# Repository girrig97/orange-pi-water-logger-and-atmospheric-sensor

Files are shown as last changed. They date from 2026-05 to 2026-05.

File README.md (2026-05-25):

# Orange Pi Water Logger

This starter project logs water-condition readings to a CSV file on the Orange Pi microSD card every 6 hours.

Variant branch: this branch includes shared logger code for Orange Pi Zero 3 and Orange Pi 5 Max. The EC25-AU cellular modem, SMS alerts, server status updates, and daily status reporting are optional and are skipped automatically when no modem/SIM is detected. See [docs/orange-pi-5-max-ec25-au.md](docs/orange-pi-5-max-ec25-au.md).

On the cellular branch, SMS alert recipients can be changed from the Android app using `Get SMS Numbers` and `Save SMS Numbers`.

## Design brief

Build a field-ready freshwater monitoring recorder that can run unattended from a USB power bank, store week-by-week CSV logs on microSD, and remain usable even when individual probes or optional hardware are disconnected.

Core requirements:

- Support both Orange Pi Zero 3 and Orange Pi 5 Max as the main logger.
- Use a Raspberry Pi Pico or Pico W as the always-on low-power time and power controller.
- Power the Orange Pi only when needed for scheduled logging, download mode, pairing mode, or manual checks.
- Record freshwater sensor data every 6 hours by default.
- Switch to hourly recording when barometric pressure is low or dropping quickly.
- Store records on the Orange Pi microSD card as weekly CSV files.
- Keep logging partial records if a sensor is damaged, disconnected, or not installed.
- Tag failed sensor reads with clear status values instead of stopping the logger.
- Build a sensor baseline from early successful readings so missing optional sensors do not create repeated fault alerts.
- Allow field access from an Android phone over Bluetooth for status, time sync, live readings, CSV downloads, SMS number settings, signal checks, and test SMS.
- Make cellular reporting optional. If no EC25-AU modem or usable SIM is detected, skip SMS work and continue normal logging.
- Send optional daily SMS status, server updates, and unsafe-water alerts when the EC25-AU modem is installed and ready.

Field-use behavior:

- Power-on should automatically start the correct mode without terminal access.
- Normal wake: Pico powers the Orange Pi, the logger writes one row, sends the next interval to the Pico, syncs data, and shuts down.
- Short button press: Pico starts download mode and keeps the Orange Pi awake for Bluetooth access.
- Long button hold: Pico starts pairing mode.
- 10-second hold while awake: manual power-off fallback.
- After Bluetooth download or resume, mode markers are cleared so the next wake returns to unattended logging.

Reliability considerations:

- CSV writes are flushed and fsynced.
- Weekly CSV files reduce the impact of single-file corruption.
- The UART link between Orange Pi and Pico is required for adaptive wake timing, but logger shutdown still continues if the UART notification fails.
- All grounds must be common.
- Orange Pi GPIO and ADS1115 inputs must stay within 3.3V logic/input limits.
- Probe modules need calibration before readings should be treated as meaningful.
- The enclosure, cable glands, connectors, and sensor electronics must be protected against water ingress and condensation.

## Sensors included

- pH
- TDS
- Turbidity
- DS18B20 temperature
- ORP
- Dissolved oxygen
- Ammonium ISE
- BME280 ambient temperature, humidity, and pressure

## Calculated values

- EC from TDS
- Estimated salinity
- Water clarity percent
- Dissolved oxygen saturation percent
- Toxic ammonia NH3 estimate from ammonium, pH, and temperature
- Ammonia risk label
- Overall water score and condition label
- Ambient dew point
- Air/water temperature difference
- Adaptive next logging interval from barometric pressure

## Materials

Core computer and power:

| Qty | Item | Notes |
| ---: | --- | --- |
| 1 | Orange Pi Zero 3 or Orange Pi 5 Max | Main logger, stores CSV on microSD |
| 1 | microSD card | 16GB or larger recommended |
| 1 | Raspberry Pi Pico or Pico W | Low-power timer and download-mode button controller |
| 1 | USB power bank | 10,000mAh minimum; larger is better |
| 1 | 5V relay or MOS power-switch module | Pico-controlled switch for Orange Pi 5V; rated at least 3A, preferably 5A |
| 1 | DS3231 RTC module | Keeps accurate time for the Pico controller |
| 1 | Momentary self-reset illuminated button | Use `NO` and `C` for the button signal; LED terminals are separate |
| 1 | Weatherproof enclosure | Large enough for Orange Pi, Pico, ADCs, and wiring |

Sensor and interface modules:

| Qty | Item | Notes |
| ---: | --- | --- |
| 2 | ADS1115 ADC modules | I2C analog inputs for Orange Pi |
| 1 | pH sensor board and BNC pH probe | Analog output to ADS1115 |
| 1 | TDS sensor meter V1.0 board and probe | Analog output to ADS1115 |
| 1 | Turbidity sensor module and probe | Analog output to ADS1115 |
| 1 | Waterproof DS18B20 temperature probe | Digital 1-Wire temperature |
| 1 | ORP sensor module and BNC ORP probe | Analog output to ADS1115 |
| 1 | Gravity analog dissolved oxygen sensor kit | Analog output to ADS1115 |
| 1 | NH4+ ammonium ISE probe | BNC probe |
| 1 | High-impedance ISE interface amplifier | Required between NH4+ probe and ADS1115 |
| 1 | BME280 I2C sensor module | Ambient air temperature, humidity, and barometric pressure |

Wiring and protection:

| Qty | Item | Notes |
| ---: | --- | --- |
| 1 | 4.7k resistor | DS18B20 data pull-up to 3.3V |
| Assorted | Jumper wires or hookup wire | Use reliable connectors for field use |
| Assorted | Screw terminals or waterproof connectors | Makes sensor replacement easier |
| Assorted | Heat shrink tubing | Strain relief and insulation |
| Assorted | Cable glands | For waterproof enclosure cable exits |
| As needed | Voltage divider resistors or level shifters | Required if sensor analog output can exceed 3.3V |
| 2 | UART link wires between Orange Pi and Pico | Required for download button requests and adaptive wake timing |
| Optional | Small fuse or resettable polyfuse | Protection on 5V power line |
| Optional | Desiccant pack | Helps reduce moisture in enclosure |

Calibration and maintenance:

| Qty | Item | Notes |
| ---: | --- | --- |
| 1 set | pH buffer solutions | pH 4.00, 7.00, and 10.00 |
| 1 | TDS calibration solution | Common examples: 342ppm or 1000ppm |
| 1 | ORP calibration solution | Match your ORP probe/module instructions |
| 1 | Dissolved oxygen calibration supplies | Follow Gravity DO kit instructions |
| 1 set | NH4+ ISE calibration standards | At least two known concentrations |
| 1 | Distilled or deionized water | Rinsing probes between calibration steps |
| Optional | Cleaning/storage solutions | Especially for pH, ORP, DO, and ISE probes |

## Hardware shape

Use two ADS1115 ADC boards on the Orange Pi I2C header. The code auto-detects likely I2C buses for Orange Pi Zero 3 and Orange Pi 5 Max. Set `I2C_BUS_NUMBER` only if you want to force a specific bus.

## Wiring diagram

Wiring diagram

PCB carrier design notes are in [docs/pcb-carrier-design-brief.md](docs/pcb-carrier-design-brief.md).
The first Zero 3 KiCad carrier scaffold is in [hardware/zero3-carrier](hardware/zero3-carrier).

Key things to double-check before powering on:

- The 5V power-switch module input connects to the USB power bank 5V, not to a Pico GPIO pin.
- The 5V power-switch module GND is on the common ground bus.
- Pico `GP15` drives only the power-switch trigger / enable / signal / `IN` pin.
- Pico `GP14` connects only to the download button, not to the power switch.
- ADS1115 #1 has `ADDR -> GND` for address `0x48`.
- ADS1115 #2 has `ADDR -> 3.3V` for address `0x49`.
- Any sensor analog output above 3.3V needs level scaling before the ADS1115 input.

The numbered badges in the image match the legend table below. Recheck the power-switch section carefully before building, because relay and MOS boards use different terminal names.

Corrected numbered wiring:

| Number | Correct connection |
| --- | --- |
| 1 | USB-C/power-bank 5V to the PCB input; protected 5V feeds Pico VSYS and the MOSFET switch input |
| 2 | Common GND bus to Pico GND, power-switch GND, Orange Pi GND, ADC GND, sensor GND |
| 3 | Pico `GP15` to power-switch trigger/enable input |
| 4 | Pico `GP14` to button `NO`; button `C` to common GND |
| 5 | Pico `GP4` to DS3231 SDA |
| 6 | Pico `GP5` to DS3231 SCL |
| 7 | Pico `3V3` to DS3231 VCC |
| 8 | MOSFET switched 5V output to Orange Pi 5V input, pin 2 or 4 |
| 9 | Power-switch output/common GND to Orange Pi GND, pin 6 |
| 10 | Orange Pi pin 1 `3.3V` to ADS1115 VDD and DS18B20 VCC |
| 11 | Orange Pi pin 3 SDA to both ADS1115 SDA pins |
| 12 | Orange Pi pin 5 SCL to both ADS1115 SCL pins |
| 13 | Orange Pi pin 7 PC9/GPIO7 to DS18B20 data, with 4.7k pull-up to 3.3V |
| 14 | ADS1115 #1 A0 to pH analog output |
| 15 | ADS1115 #1 A1 to TDS analog output |
| 16 | ADS1115 #1 A2 to turbidity analog output |
| 17 | ADS1115 #1 A3 to ORP analog output |
| 18 | ADS1115 #2 A0 to dissolved oxygen analog output |
| 19 | ADS1115 #2 A1 to ammonium ISE amplifier analog output |
| 20 | ADS1115 #2 A2 spare |
| 21 | ADS1115 #2 A3 spare |

Corrected wiring view:

```text
                                  USB POWER BANK
                                5V OUT      GND
                                  |          |
                                  |          +-------------------- COMMON GND BUS
                                  |                               |
                                  v                               |
                    +-----------------------------+               |
                    | Raspberry Pi Pico / Pico W  |               |
                    |                             |               |
                    | VSYS/USB <- 5V power bank   |               |
                    | GND ------ COMMON GND BUS --+               |
                    | GP15 ---- power enable ----------------+    |
                    | GP14 ---- button NO/C ---- GND          |    |
                    | GP4  ---- DS3231 SDA                   |    |
                    | GP5  ---- DS3231 SCL                   |    |
                    | 3V3  ---- DS3231 VCC                   |    |
                    +-----------------------------+           |    |
                                                              |    |
                                  +---------------------------+    |
                                  v                                |
                         +------------------+                      |
                         | 5V POWER SWITCH   |                      |
                         | TRIG/EN <- GP15  |                      |
                         | IN+ <- bank 5V   |                      |
                         | IN- <- GND bus --+----------------------+
                         | OUT+ -> OPi 5V   |
                         | OUT- -> OPi GND  |
                         +------------------+
                                  |
                                  v
                    +-----------------------------+
                    | Orange Pi Zero 3            |
                    | Pin 2/4 5V <- switched 5V   |
                    | Pin 6 GND  -> common GND    |
                    | Pin 1 3.3V -> 3.3V rail     |
                    | Pin 3 SDA  -> I2C SDA rail  |
                    | Pin 5 SCL  -> I2C SCL rail  |
                    | Pin 7 PC9  -> DS18B20 DATA  |
                    +-----------------------------+
                         |        |        |
                         |        |        +---------------- I2C SCL rail
                         |        +------------------------- I2C SDA rail
                         +---------------------------------- 3.3V rail

      3.3V rail ----------------+----------------------+----------------------+
                                |                      |                      |
                                v                      v                      v
                    +-------------------+  +----------------------+  +----------------------+
                    | ADS1115 #1        |  | ADS1115 #2           |  | DS18B20 temp probe   |
                    | ADDR -> GND       |  | ADDR -> 3.3V/VDD     |  | Red/VCC -> 3.3V      |
                    | address 0x48      |  | address 0x49         |  | Black/GND -> GND     |
                    | VDD -> 3.3V       |  | VDD -> 3.3V          |  | Yellow/DATA -> OPi 7 |
      GND bus ---->| GND -> GND        |  | GND -> GND           |  | 4.7k DATA -> 3.3V    |
      SDA rail --->| SDA -> OPi pin 3   |  | SDA -> OPi pin 3     |  +----------------------+
      SCL rail --->| SCL -> OPi pin 5   |  | SCL -> OPi pin 5     |
                    | A0 <- pH AO        |  | A0 <- DO AO          |
                    | A1 <- TDS AO       |  | A1 <- NH4 ISE AO     |
                    | A2 <- turbidity AO |  | A2 spare             |
                    | A3 <- ORP AO       |  | A3 spare             |
                    +-------------------+  +----------------------+
                              ^     ^     ^     ^            ^          ^
                              |     |     |     |            |          |
                              |     |     |     |            |          |
       +----------------------+     |     |     |            |          |
       |                            |     |     |            |          |
+-------------+              +-------------+ +-------------+ +-------------+ +------------------+
| pH module   |              | TDS module  | | Turbidity   | | ORP module  | | Gravity DO       |
| VCC -> 5V*  |              | VCC -> 5V*  | | VCC -> 5V*  | | VCC -> 5V*  | | VCC -> 3.3-5V*   |
| GND -> GND  |              | GND -> GND  | | GND -> GND  | | GND -> GND  | | GND -> GND       |
| AO -> A0    |              | AO -> A1    | | AO -> A2    | | AO -> A3    | | AO -> ADS #2 A0  |
| BNC -> probe|              | Probe socket| | Probe socket| | BNC -> probe| | Probe socket     |
+-------------+              +-------------+ +-------------+ +-------------+ +------------------+

                          +--------------------------+
                          | NH4+ ISE interface amp   |
                          | VCC -> module requirement|
                          | GND -> common GND        |
                          | BNC -> NH4+ ISE probe    |
                          | AO  -> ADS1115 #2 A1     |
                          +--------------------------+

                          +--------------------------+
                          | DS3231 RTC module        |
                          | VCC -> Pico 3V3          |
                          | GND -> common GND        |
                          | SDA -> Pico GP4          |
                          | SCL -> Pico GP5          |
                          +--------------------------+

                          +--------------------------+
                          | Momentary button         |
                          | NO -> Pico GP14          |
                          | C  -> common GND         |
                          +--------------------------+

* If a module's analog output can exceed 3.3V, add a voltage divider or level
  scaling before the ADS1115 input.
```

All grounds must be common:

```text
Power bank GND
Pico GND
power-switch GND
Orange Pi GND
ADS1115 GND
sensor module GND
DS3231 GND
DS18B20 GND
```

Do not power the Orange Pi directly from a Pico pin. The Pico only controls the relay/MOS power-switch trigger input.

### Power switch wiring options

The code expects a simple active-high control signal:

```text
Pico GP15 HIGH -> Orange Pi power on
Pico GP15 LOW  -> Orange Pi power off
```

For a relay module, use the relay contacts to switch the Orange Pi 5V positive line:

| Relay terminal | Connect to |
| --- | --- |
| `VCC` | module supply voltage, usually 5V unless your board says otherwise |
| `GND` | common GND |
| `IN`, `SIG`, or `TRIG` | Pico `GP15` |
| `COM` | USB power bank 5V |
| `NO` | Orange Pi 5V pin 2 or 4 |
| `NC` | leave unused |

Use `NO`, not `NC`, so the Orange Pi is normally off until the Pico enables it.

For a MOS switch board, use the switched output terminals:

| MOS switch terminal | Connect to |
| --- | --- |
| `VIN+`, `V+`, or `DC+` | USB power bank 5V |
| `VIN-`, `V-`, or `DC-` | common GND |
| `TRIG`, `PWM`, `IN`, or `EN` | Pico `GP15` |
| `VOUT+`, `OUT+`, or `LOAD+` | Orange Pi 5V pin 2 or 4 |
| `VOUT-`, `OUT-`, or `LOAD-` | Orange Pi GND |

Some MOS boards are low-side switches, meaning they only switch the ground side. They can work for testing, but a relay contact or high-side switch is safer for field use because it avoids back-powering through UART or sensor wires.

## Module wiring summary

| Module | Power | Ground | Signal to Orange Pi/ADC | Probe connection |
| --- | --- | --- | --- | --- |
| pH board | 5V or module spec | common GND | AO to ADS1115 #1 A0 | pH BNC probe |
| TDS board | 5V or module spec | common GND | AO to ADS1115 #1 A1 | TDS probe socket |
| Turbidity board | 5V or module spec | common GND | AO to ADS1115 #1 A2 | turbidity probe socket |
| ORP board | 5V or module spec | common GND | AO to ADS1115 #1 A3 | ORP BNC probe |
| Gravity dissolved oxygen board | 3.3V-5V, module spec | common GND | AO to ADS1115 #2 A0 | DO probe socket |
| NH4+ ISE interface amplifier | module spec | common GND | AO to ADS1115 #2 A1 | NH4+ ISE BNC probe |
| DS18B20 waterproof temp probe | Orange Pi 3.3V | common GND | DATA to Orange Pi pin 7 | built in |
| BME280 ambient sensor | Orange Pi 3.3V | common GND | SDA pin 3, SCL pin 5 | air temp, humidity, pressure |
| ADS1115 #1 | Orange Pi 3.3V | common GND | SDA pin 3, SCL pin 5 | A0-A3 analog inputs |
| ADS1115 #2 | Orange Pi 3.3V | common GND | SDA pin 3, SCL pin 5 | A0-A3 analog inputs |
| DS3231 RTC | Pico 3.3V | common GND | SDA GP4, SCL GP5 | none |
| 5V relay or MOS power switch | power bank 5V input | common GND | trigger/EN from Pico GP15 | switched 5V to Orange Pi |
| Momentary button switch | none | `C` to common GND | `NO` to Pico GP14 | none |
| Required UART link | Orange Pi 3.3V UART logic | common GND | Orange Pi TX to Pico GP1/RX, Orange Pi RX to Pico GP0/TX | download mode and adaptive wake timing |

## Orange Pi Zero 3 header wiring

| Orange Pi physical pin | Function | Connect to |
| --- | --- | --- |
| Pin 1 | 3.3V | ADS1115 VDD, DS18B20 VCC |
| Pin 3 | I2C3 SDA | ADS1115 #1 SDA, ADS1115 #2 SDA |
| Pin 5 | I2C3 SCL | ADS1115 #1 SCL, ADS1115 #2 SCL |
| Pin 6 | GND | ADS1115 GND and all sensor GND wires |
| Pin 7 | GPIO PC9 | DS18B20 data |
| Pin 2 or 4 | 5V | Sensor boards that require 5V input |

Add a 4.7k resistor between DS18B20 data and 3.3V.

## ADS1115 address setup

| ADC board | ADDR pin | I2C address |
| --- | --- | --- |
| ADS1115 #1 | GND | `0x48` |
| ADS1115 #2 | VDD | `0x49` |

## ADS1115 sensor wiring

| Sensor | ADC input |
| --- | --- |
| pH | ADS1115 #1 A0 |
| TDS | ADS1115 #1 A1 |
| Turbidity | ADS1115 #1 A2 |
| ORP | ADS1115 #1 A3 |
| Dissolved oxygen | ADS1115 #2 A0 |
| Ammonium ISE interface | ADS1115 #2 A1 |

The ammonium ISE needs a high-impedance ISE interface board. Do not connect the electrode directly to the ADC.

Important: if the ADS1115 boards are powered from 3.3V, every analog input must stay between 0V and 3.3V. If a sensor board outputs 0-5V, use a voltage divider or level-scaling circuit before the ADS1115 input.

## Orange Pi setup

Enable I2C3:

```bash
sudo orangepi-config
```

Then go to `System`, `Hardware`, enable `ph-i2c3`, save, and reboot.

After reboot, check the ADC boards. For a Zero 3 this is usually bus 3; for a 5 Max use the bus you enabled, or run `ls /dev/i2c-*` and scan the likely buses:

```bash
sudo apt update
sudo apt install -y i2c-tools python3-smbus
i2cdetect -y 3
```

You should see:

```text
0x48
0x49
```

The code reads ADS1115 #1 at `0x48` and ADS1115 #2 at `0x49`. If `I2C_BUS_NUMBER` is unset, it auto-detects likely Orange Pi I2C buses.

## BME280 ambient sensor

Wire the BME280 to the same Orange Pi I2C bus as the ADS1115 boards:

| BME280 pin | Orange Pi header function |
| --- | --- |
| VCC/VIN | Pin 1 `3.3V` |
| GND | Pin 6 `GND` |
| SDA | Pin 3 `I2C SDA` |
| SCL | Pin 5 `I2C SCL` |

The BME280 usually appears at `0x76` or `0x77`. The logger tries both.

Install the Python libraries:

```bash
sudo apt install -y python3-pip
pip3 install smbus2 RPi.bme280 pyserial
```

The CSV adds:

```text
air_temperature_c
air_humidity_percent
air_pressure_hpa
dew_point_c
air_water_temp_difference_c
next_interval_seconds
```

## Sensor fault handling

If a sensor is damaged, disconnected, or not responding, the logger keeps running. The affected raw value and dependent calculated values are left blank in the CSV, and the matching status column explains why.

Status columns include:

```text
temperature_status
ph_status
tds_status
turbidity_status
orp_status
dissolved_oxygen_status
ammonium_ise_status
air_sensor_status
```

Common status tags:

| Tag | Meaning |
| --- | --- |
| `ok` | Sensor reading worked |
| `ds18b20_not_found` | Temperature probe was not detected |
| `ds18b20_crc_failed` | Temperature probe responded with a bad checksum |
| `ads1115_0x48_not_found_or_i2c_failed` | First ADS1115 board did not respond |
| `ads1115_0x49_not_found_or_i2c_failed` | Second ADS1115 board did not respond |
| `ads1115_0x48_channel_0_read_failed` | Specific ADC channel read failed |
| `partial_read_failure` | Some samples worked and some failed |
| `bme280_not_found_or_not_responding` | Ambient air sensor did not respond |
| `bme280_library_missing` | BME280 Python library is not installed |

Example: if the ORP probe board is disconnected, `orp_voltage` and `orp_mv` will be blank, while `orp_status` will explain the fault.

## Adaptive low-pressure logging

By default:

```text
pressure >= 1000 hPa -> next recording in 6 hours
pressure < 1000 hPa  -> next recording in 1 hour
pressure drop >= 6 hPa over recent 24h -> next recording in 1 hour
```

The Orange Pi writes the next interval to:

```text
/home/orangepi/water-logger/records/next_interval_seconds.txt
```

The UART link is required. The Pico uses it to request download mode, and after each reading the Orange Pi sends the next wake interval back to the Pico:

```text
NEXT_INTERVAL=3600
```

or:

```text
NEXT_INTERVAL=21600
```

Required UART wiring:

| Signal | Connect |
| --- | --- |
| Orange Pi UART TX | Pico GP1/RX |
| Orange Pi UART RX | Pico GP0/TX |
| Orange Pi GND | Pico GND |

The logger records the row even if this UART link is unavailable, then logs a warning and continues shutdown so the power bank is not drained. The Pico treats a missing `NEXT_INTERVAL` as a fault and retries in 1 hour. The code defaults to Orange Pi serial port `/dev/ttyS5`. If your enabled UART appears under another name, set:

```bash
export PICO_SERIAL_PORT=/dev/ttyS1
```

For I2C, auto-detection usually avoids board-specific edits. To force a bus:

```bash
export I2C_BUS_NUMBER=3   # common Zero 3 setup
export I2C_BUS_NUMBER=5   # example 5 Max setup
```

## microSD record path

Records are stored beside the project in a `records` folder. The logger starts a new CSV file each ISO calendar week to keep files smaller and reduce the impact of any single-file corruption.

If the project is copied to:

```text
/home/orangepi/water-logger
```

weekly CSV files will be created like:

```text
/home/orangepi/water-logger/records/water_conditions_2026_week_20.csv
/home/orangepi/water-logger/records/water_conditions_2026_week_21.csv
```

The download-mode marker lives in the same folder:

```text
/home/orangepi/water-logger/records/DOWNLOAD_MODE
```

## Run

```bash
python3 water_logger.py
```

The CSV files will be created as weekly files:

```text
water_conditions_YYYY_week_WW.csv
```

on the microSD card.

## Low power mode

For USB power bank use, run one reading at a time:

```bash
python3 water_logger.py --once
```

Then schedule it every 6 hours with a systemd timer or cron job. This avoids keeping the Python program awake all day, although the Orange Pi itself is still powered unless you add timed power-control hardware.

Example cron line:

```cron
0 */6 * * * /usr/bin/python3 /home/orangepi/water_logger.py --once
```

For much longer battery life, use a timer power switch, RTC power module, or small microcontroller to turn the Orange Pi on every 6 hours, let it log once, then shut it down.

With timed power hardware, run:

```bash
python3 water_logger.py --once --shutdown-after
```

## Pico power controller

Use `pico_power_controller.py` on a Raspberry Pi Pico or Pico W to switch Orange Pi power.

| Pico pin | Connect to |
| --- | --- |
| GP15 | On-board MOSFET/load-switch gate-driver input |
| GP14 | Momentary button `NO`; button `C` to GND |
| GP0/TX | Orange Pi UART RX |
| GP1/RX | Orange Pi UART TX |
| GP4 | DS3231 SDA |
| GP5 | DS3231 SCL |
| GP13 | Strongly recommended: Orange Pi ready/shutdown GPIO |
| 3V3 | DS3231 VCC |
| GND | DS3231 GND, button `C`, MOSFET gate-driver GND |
| VSYS or 5V USB input | Always-on protected 5V from the board USB-C input |

One USB-C PD input can power both the Pico and Orange Pi Zero 3. Wire it as:

```text
USB-C PD input -> PD sink controller -> negotiated 9V rail
USB-C PD input -> PD sink controller -> buck regulator -> Pico always-on 5.1V/VSYS
USB-C PD input -> PD sink controller -> buck regulator -> high-side MOSFET -> Orange Pi 5V input
```

The Pico stays powered all the time. The Orange Pi 5V input is powered only
through the MOSFET/load-switch path. For the PCB version, use a USB-C PD sink
controller and a 5A buck regulator so the board can request 9V from the power
bank and generate its own stable 5.1V rail. A 30W or larger USB-C PD power bank
is the sensible minimum for the Zero 3 build.

Normal mode:

- Pico powers the Orange Pi every 6 hours.
- Orange Pi runs `water_logger.py --once --shutdown-after`.
- Pico cuts Orange Pi power after the logging window.

Wire the Orange Pi ready/shutdown GPIO to Pico `GP13` if possible. Without it, the Pico uses the full scheduled safety window before cutting power; with it, the Pico can cut power shortly after Linux has finished and shut down cleanly.

Download mode:

- Press the Pico button once and release.
- Pico powers the Orange Pi, keeps it on, and sends a UART download-mode request.
- The status LED flashes slowly while the Orange Pi is awake for download mode.
- Download the CSV over Bluetooth or WiFi.
- Hold the button for 10 seconds while awake to cut power manually.
- A 1-hour timeout turns it off as a fallback.

Pairing mode:

- Hold the Pico button for 2 seconds while the logger is asleep.
- Pico powers the Orange Pi, keeps it on, and sends a UART pairing-mode request.
- The status LED flashes quickly while the Orange Pi is awake for pairing mode.
- The Orange Pi makes Bluetooth discoverable and pairable, then starts the same Bluetooth records server.
- Pair your phone, then use the Android app or Bluetooth terminal commands.

The momentary self-reset button terminals are:

| Button terminal | Use |
| --- | --- |
| `NO` | Connect to Pico `GP14` |
| `C` | Connect to common GND |
| `NC` | Leave unused |
| `A` or `+` | LED positive, optional |
| `LED` or `-` | LED negative, optional |

Use `NO` and `C`, so the Pico input is normally open and only connects to GND while pressed. Do not use the self-locking/latching version for this behavior.

The button LED is separate from the button switch. The code flashes `STATUS_LED_PIN`, which defaults to the Pico onboard LED on `GP25`. To flash the button's built-in LED instead, change `STATUS_LED_PIN` in `pico_power_controller.py` to a spare Pico GPIO and wire the LED terminals according to the voltage rating of your button LED. If the LED is bare 3V style, use a current-limiting resistor, for example 330 ohms. If it is a 5V/12V/24V button LED, do not connect it directly to a Pico GPIO unless the listing says it is safe at 3.3V.

Button behavior summary:

| Button action | Result | LED pattern |
| --- | --- | --- |
| Short press and release | Download mode | Slow flash |
| Hold for 2 seconds from sleep | Bluetooth pairing mode | Fast flash |
| Hold for 10 seconds while awake | Manual power-off fallback | LED off after power cut |

The button is the normal way to enter download or pairing mode. As a fallback, you can manually create this empty file before boot:

```text
DOWNLOAD_MODE
```

For pairing mode fallback, create:

```text
PAIRING_MODE
```

When the boot wrapper sees the Pico request, `records/DOWNLOAD_MODE`, or `records/PAIRING_MODE`, it starts the Bluetooth serial download server instead of doing the normal unattended log-and-shutdown cycle.

## Boot service for timed power

Copy this project to:

```text
/home/orangepi/water-logger
```

Then install the boot service:

```bash
sudo cp orange_pi_boot_logger.service /etc/systemd/system/
sudo systemctl enable orange_pi_boot_logger.service
```

When the Pico powers the Orange Pi, the service runs one reading and shuts the Orange Pi down unless the microSD records folder contains `DOWNLOAD_MODE`.

If `DOWNLOAD_MODE` or `PAIRING_MODE` exists, the boot wrapper starts a Bluetooth serial download server instead of shutting down. `PAIRING_MODE` also asks BlueZ to make the Orange Pi Bluetooth adapter discoverable and pairable.

Bluetooth commands:

| Command | What it does |
| --- | --- |
| `status` | Shows weekly file count, latest file, total size, and download-mode state |
| `latest` | Sends the newest CSV row |
| `settime 2026-05-12T14:30:00+10:00` | Sets Orange Pi time from your phone, then logs a fresh reading |
| `log` | Logs one fresh reading using the current Orange Pi time |
| `live` | Streams unsaved live readings every 5 seconds |
| `stop` | Stops live reading stream |
| `sms` | Shows configured SMS alert recipient numbers |
| `setsms +61400111222,+61400999888` | Sets SMS alert recipient numbers |
| `clearsms` | Clears SMS alert recipient numbers |
| `resetbaseline` | Clears the sensor-failure baseline after sensor repair or reconfiguration |
| `signal` | Shows EC25 network generation and signal level on the cellular branch |
| `testsms` | Sends a test SMS to configured recipients on the cellular branch |
| `download` | Sends the newest weekly CSV, deletes `DOWNLOAD_MODE`, syncs, and shuts down |
| `download all` | Sends all weekly CSV files, deletes `DOWNLOAD_MODE`, syncs, and shuts down |
| `resume` | Deletes `DOWNLOAD_MODE`/`PAIRING_MODE` and shuts down without downloading |

That means after a successful Bluetooth `download`, the next Pico wake returns to normal 6-hour logging automatically.

## Download logs from a phone over Bluetooth

You can use the included Android companion app in `android-app/`, or use a generic Bluetooth serial terminal.

### Android companion app

The Android app provides buttons for:

```text
Connect
System Status
Record Count
List Record Times
Latest Reading
Start Live Readings
Stop Live Readings
Sync Time + Log
Log Fresh Reading
Download Latest Week
Download All Weeks
Resume Normal Logging
```

The app connects to the Orange Pi Bluetooth serial service and sends the same commands documented below.

To build the APK:

1. Push the project to GitHub.
2. Open the repository on GitHub.
3. Go to `Actions`.
4. Run `Build Android APK`, or wait for it to run after changes to `android-app/`.
5. Download the `water-logger-companion-debug-apk` artifact.
6. Install `app-debug.apk` on your Android phone.

On the phone, you may need to allow:

```text
Install unknown apps
Bluetooth permission
```

Before opening the app, pair your phone with the Orange Pi in Android Bluetooth settings.

### Bluetooth terminal fallback

Use an Android Bluetooth serial terminal app. Search for one of these:

```text
Serial Bluetooth Terminal
Bluetooth Terminal
RFCOMM Bluetooth terminal
```

Phone workflow:

1. Press the Pico download-mode button.
2. Wait for the Orange Pi to boot.
3. Pair your phone with the Orange Pi through Bluetooth settings.
4. Open the Bluetooth terminal app and connect to `OrangePi Water Records`.
5. Send `status` to check the connection.
6. Send `download` for the newest weekly CSV, or `download all` for every weekly CSV.

After `download` or `download all`, the Orange Pi deletes `DOWNLOAD_MODE`, syncs the microSD, shuts down, and the next Pico wake returns to normal logging.

The button request uses the required UART link from Pico to Orange Pi. As a fallback, you can also manually create this file before boot:

```text
records/DOWNLOAD_MODE
```

If your phone has not been paired before, hold the button for 2 seconds from sleep instead of short-pressing it. The fast LED flash means pairing mode is active. Pair the phone first, then open the Android app or Bluetooth terminal.

## Sync time from phone over Bluetooth

In download mode, the Orange Pi starts the Bluetooth command server before taking an extra download-mode reading. This lets your phone set the clock first so the new log row has true time.

Send this from the Bluetooth terminal:

```text
settime 2026-05-12T14:30:00+10:00
```

Use your actual phone time and timezone offset. For Brisbane/Australia standard time, the offset is usually:

```text
+10:00
```

After `settime`, the Orange Pi:

1. Sets its system clock.
2. Tries to write hardware clock time with `hwclock -w`.
3. Records one fresh sensor row.
4. Keeps Bluetooth open so you can send `download`.

Example field sequence:

```text
status
settime 2026-05-12T14:30:00+10:00
latest
download
```

If you only want to set time and take a fresh reading without downloading yet, send:

```text
settime 2026-05-12T14:30:00+10:00
```

If the time is already correct and you only want a fresh row:

```text
log
```

## Live readings

Live readings let you check the sensors without adding rows to the weekly CSV.

In the Android app, press:

```text
Start Live Readings
```

The Orange Pi streams one fresh unsaved reading every 5 seconds. Press:

```text
Stop Live Readings
```

to stop the stream.

From a Bluetooth terminal, use:

```text
live
```

and then:

```text
stop
```

Install Bluetooth serial support:

```bash
sudo apt install -y bluetooth bluez python3-bluez
sudo systemctl enable bluetooth
sudo systemctl start bluetooth
```

## Important

The pH, TDS, turbidity, ORP, dissolved oxygen, and ammonium calculations contain starter calibration values. You will need to calibrate each probe before trusting the numbers.

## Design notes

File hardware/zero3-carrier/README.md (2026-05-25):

# Orange Pi Zero 3 Water Logger Carrier PCB

This KiCad project is the first-pass PCB carrier for the Orange Pi Zero 3
version of the water logger.

Status: **ERC + DRC clean, fully routed by Freerouting, Gerbers exported under `fabrication/pcbway/`. Do not order without first reviewing the switching power supply layout against the TPS54531 reference design** — see `fabrication/pcbway/REVIEW-BEFORE-ORDER.md`.

The board is intended to act as a shield/carrier/interface board:

- Orange Pi Zero 3 connects through its 26-pin header.
- Raspberry Pi Pico plugs into 2 x 20 headers.
- DS3231, BME280, and ADS1115 boards can plug into module headers.
- Water sensors connect through labelled screw terminals or JST-style headers.
- An integrated high-side 5V MOSFET/load-switch section switches Orange Pi power.
- DS18B20 has a 4.7k pull-up footprint.

## Files

| File | Purpose |
| --- | --- |
| `zero3-water-logger-carrier.kicad_pro` | KiCad project |
| `zero3-water-logger-carrier.kicad_sch` | R1 schematic draft with PD, buck, switch, Pico, Orange Pi, ADC, sensor, RTC, and ambient headers |
| `zero3-water-logger-carrier.kicad_pcb` | Board outline, assigned footprints, schematic nets, and placement draft |
| `water_logger_generated.kicad_sym` | Local generated KiCad symbol library used by the schematic |
| `sym-lib-table` | Project symbol-library table for the generated `WL` library |
| `zero3-water-logger-carrier-pinout.csv` | Pin/net planning table |
| `selected-parts-bom.csv` | Selected revision-1 PD/buck/MOSFET parts and values |
| `fabrication-readiness.md` | PCBWay/Gerber readiness checklist |
| `generate_schematic.py` | Regenerates the KiCad schematic + symbol library + pinout CSV from the selected net plan |
| `generate_pcb.py` | Regenerates the KiCad PCB placement, net assignments, and dual-layer GND pours from the selected net plan |
| `route_with_freerouting.py` | One-command auto-routing: exports DSN, runs Freerouting, imports SES, refills zones, re-runs DRC |
| `validate_design.py` | ERC + DRC + pinout-CSV format gate; runs before committing PCB changes |
| `manual-routing-guide.md` | Step-by-step hand-routing instructions, including the required TPS54531 and high-side MOSFET datasheet routes |

Current schematic check: `kicad-cli sch erc` reports **0 violations**. Current
PCB DRC reports **0 violations** and **0 unconnected items** after
Freerouting routed all 83 signal/power nets. The full PCBWay upload package
(Gerbers, drill, schematic PDF, review checklist) is in
`fabrication/pcbway/`, also zipped as `fabrication/zero3-water-logger-carrier-R1.zip`.

## Current Placement

The R1 board file contains schematic-synced footprints and net assignments for:

- Orange Pi Zero 3 26-pin header.
- Raspberry Pi Pico 2 x 20 socket.
- ADS1115 #1 and #2 module headers.
- DS18B20, BME280, and DS3231 module headers.
- Six 3-pin analog sensor terminals: pH, TDS, turbidity, ORP, dissolved oxygen, and ammonium ISE amp.
- Download button header with switch contacts and optional LED terminals.
- Spare analog header for the unused ADS1115 #2 A2/A3 channels.
- 4.7k DS18B20 pull-up resistor.
- Integrated USB-C PD input, TPS54531 buck regulator, and high-side 5V MOSFET
  switch section.

The PCB is intentionally left unrouted. Route and review the power section in
KiCad before generating Gerbers. The CH224K package/pin mapping must be checked
against the exact part datasheet before assembly.

## Integrated 5V Switch

The board now plans for an on-board high-side 5V switch instead of an external
relay/MOSFET module.

Power path:

```text
USB-C PD input -> PD sink controller -> negotiated 9V rail
                -> buck regulator -> protected 5.1V rail
                                  -> Pico always-on VSYS/5V
                                  -> P-channel MOSFET -> switched 5V rail
```

Control path:

```text
Pico GP15 -> gate-driver transistor/MOSFET -> P-channel MOSFET gate
```

Default state is off. The P-channel MOSFET gate is pulled up to fused 5V. When
Pico GP15 goes high, the small gate-driver device pulls the P-channel gate low
and enables switched 5V to the Orange Pi.

Planned parts:

| Ref | Function | Requirement |
| --- | --- | --- |
| `J14` | USB-C PD input | USB-C 16-pin receptacle, HRO TYPE-C-31-M-12 class |
| `U1` | USB-C PD sink controller | CH224K, strapped for fixed 9V request |
| `D1` | VBUS TVS diode | USB/PD-rated input surge protection |
| `F1` | Input protection | Resettable fuse/polyfuse on negotiated PD input rail |
| `U2` | Buck regulator | TPS54531DDA 5A buck regulator |
| `L1` | Buck inductor | 4.7uH shielded inductor rated at least 6A |
| `D2` | Buck catch diode | CDBC540-G or equivalent 5A/40V Schottky |
| `CIN1`, `CIN2` | Buck/input capacitors | 4.7uF 50V X7R near `U2` |
| `CIN3` | Buck high-frequency bypass | 10nF 50V near `U2` |
| `COUT1`, `COUT2` | 5.1V output capacitors | 47uF low-ESR output capacitors |
| `RFB1`, `RFB2` | Buck feedback divider | TPS54531 example values: 10.2k / 1.96k |
| `REN1`, `REN2` | Buck enable divider | TPS54531 8V minimum input example values: 665k / 130k |
| `RCOMP1`, `CCOMP1`, `CCOMP2` | Buck compensation | TPS54531 example compensation network |
| `Q1` | High-side switch | AO4407A P-channel MOSFET, SOIC-8 |
| `Q2` | Gate driver | 2N7002 N-MOSFET, SOT-23, driven by Pico GP15 |
| `R2` | Gate pull-up | 100k from Q1 gate to fused 5V, keeps switch off |
| `R3` | Gate drive resistor | 1k between Pico GP15 and Q2 gate/base |
| `R4` | Driver pulldown | 100k from Q2 gate/base to GND |
| `C1` | Switched rail bulk cap | 470uF-1000uF, voltage rating at least 10V |

One USB-C port can power both boards. The Pico is connected to the protected
5.1V rail before the MOSFET so it stays awake. The Orange Pi Zero 3 is connected
only to the switched 5V rail after Q1 so the Pico can turn it off between logs.

Use a USB-C PD power bank or charger that can provide at least 30W. The target
PD profile is `9V 3A` or better, feeding a 5.1V buck rail. The TPS54531 design
uses an 8V minimum input example, so non-PD 5V fallback is not supported by this
revision.

Before ordering, verify the exact `J14`, `U1`, `U2`, `Q1`, and `Q2` pinouts
against the chosen footprints. PD controllers, buck regulators, USB-C
connectors, and MOSFET pin order are not universal.

## Revision 1 Scope

The first PCB order should keep modules replaceable:

- Socket the Pico.
- Socket the ADS1115 modules.
- Socket the DS3231 module.
- Use external sensor boards for pH, TDS, turbidity, ORP, DO, and ammonium ISE.
- Keep the EC25 modem off this PCB.

Do not order until:

- Schematic symbols and PCB footprints for the selected PD/buck/MOSFET parts
  are placed and reviewed.
- Terminal block pitch is chosen.
- The Zero 3 header clearance is checked against the actual board.
- The schematic ERC and PCB DRC pass.
- PCB DRC reports zero unconnected items after routing.
- Gerbers are opened in an independent Gerber viewer.

## Recommended PCBWay Settings

- 2 layers.
- FR-4.
- 1.6mm thickness.
- 1oz copper minimum; 2oz preferred if switching Orange Pi current on-board.
- Green solder mask unless you prefer another colour.
- HASL lead-free or ENIG.
- Use conservative rules: 0.20mm trace/space for signals, much wider for 5V/GND.

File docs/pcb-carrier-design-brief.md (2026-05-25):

# PCB Carrier Design Brief

This project can use a custom PCB, but the safest first revision should be a
carrier/interface board, not a full custom Orange Pi replacement.

The Orange Pi, Pico, RTC, sensor modules, and modem should remain replaceable
modules connected by headers or screw terminals. This keeps the board easier to
assemble, repair, and revise after field testing.

## Recommended PCB Type

Build a **water-logger carrier PCB** with:

- Orange Pi header/cable connector.
- Raspberry Pi Pico socket or header.
- DS3231 RTC module socket.
- Two ADS1115 module sockets.
- High-side 5V MOSFET/load-switch circuit for Orange Pi power.
- 4.7k DS18B20 pull-up resistor.
- Screw terminals or JST connectors for sensors.
- Common ground and 3.3V distribution.
- UART link between Pico and Orange Pi.
- Optional Orange Pi ready/shutdown GPIO input to Pico GP13.

Do **not** solder the Orange Pi directly to the board on revision 1. Use headers
or a short ribbon cable so the same PCB can work with either:

- Orange Pi Zero 3 26-pin header.
- Orange Pi 5 Max enabled GPIO/I2C/UART header pins.

## Board Strategy

There are two practical approaches.

### Option A: Universal Interface Board

Use labelled screw terminals or 2.54mm headers for these Orange Pi signals:

| Signal | Purpose |
| --- | --- |
| 5V switched input to Orange Pi | Powers Orange Pi through Pico-controlled switch |
| Orange Pi GND | Common ground |
| Orange Pi 3.3V | Powers ADC/sensor logic if current budget allows |
| Orange Pi I2C SDA | ADS1115 and BME280 data |
| Orange Pi I2C SCL | ADS1115 and BME280 clock |
| Orange Pi UART TX | Sends interval/status data to Pico GP1/RX |
| Orange Pi UART RX | Receives Pico download/pairing requests from GP0/TX |
| Orange Pi DS18B20 GPIO | 1-Wire temperature data |
| Optional Orange Pi ready GPIO | Lets Pico cut power sooner after shutdown |

This is the best first revision because it avoids board-specific header mistakes.

### Option B: Dual-Footprint Board

Place both Orange Pi header footprints on the PCB:

- 26-pin Zero 3 footprint.
- 40-pin or chosen header footprint for Orange Pi 5 Max.

Only populate/connect one at a time. This is cleaner once pin assignments are
confirmed, but it is easier to get wrong before bench testing.

## Power Architecture

Recommended power path:

```text
USB-C PD power bank / charger
-> USB-C receptacle
-> USB-C PD sink controller, fixed 9V request preferred
-> input protection and fuse
-> 9V PD rail
-> 5.1V buck regulator
-> protected 5.1V rail
   -> Pico always-on VSYS/5V
   -> high-side MOSFET/load switch
      -> switched 5V to Orange Pi
```

Requirements:

- USB-C PD source rated at least 30W for Zero 3.
- Use a fixed 9V PD request for revision 1. 9V is common and keeps cable input
  current lower than a raw 5V design.
- Feed all electronics from a local 5.1V buck regulator after PD negotiation.
- Select a buck regulator design target of 5A output so the Orange Pi, Pico,
  sensors, and startup peaks have margin.
- Use a high-side switch if possible. Avoid low-side switching for the final PCB.
- Use wide copper pours for 5V and GND.
- Add test pads for USB VBUS, negotiated PD rail, regulated 5.1V, switched 5V,
  3.3V, GND, SDA, SCL, UART TX/RX.
- Add a fuse or resettable polyfuse on the PD input rail.
- Add a TVS diode at USB VBUS.
- Add buck input/output capacitors, inductor, feedback resistors, and catch
  diode if the selected regulator is non-synchronous.

Suggested switch parts/classes:

- Integrated high-side load switch rated 5A or higher.
- P-channel MOSFET high-side switch with gate driver/transistor.
- Automotive-style high-side switch module footprint if using a replaceable module.

Do not use a relay coil on the PCB unless power use is acceptable. A relay can
work, but a MOSFET/load switch is quieter and more efficient.

The preferred revision 1 board should use one USB-C input for both boards:

- USB-C PD controller negotiates the input rail, preferably 9V.
- Buck regulator converts the negotiated PD rail to protected 5.1V.
- Pico receives protected always-on 5.1V before the MOSFET.
- Orange Pi receives switched 5V after the MOSFET.
- The MOSFET source connects to protected 5.1V.
- The MOSFET drain connects to `OPI_5V_SW`.
- Pico `GP15` drives a small transistor/MOSFET that pulls the high-side
  MOSFET gate low to turn Orange Pi power on.
- A gate pull-up keeps the Orange Pi off while the Pico boots or is unpowered.

Recommended PD front-end classes:

| Function | Practical part class |
| --- | --- |
| USB-C receptacle | HRO TYPE-C-31-M-12 class reinforced USB-C receptacle |
| PD sink controller | CH224K fixed-voltage controller strapped for 9V |
| Buck regulator | TPS54531DDA 28V input 5A buck, with layout copied closely from datasheet/reference design |
| High-side MOSFET | AO4407A P-channel MOSFET, SOIC-8 |
| Gate driver | 2N7002 N-MOSFET, SOT-23 |
| Input protection | VBUS TVS diode and resettable fuse |
| Output protection | Bulk capacitance on switched 5V rail and test pads for measurement |

Do not route the buck regulator casually. Use the selected regulator datasheet
layout exactly: short switch loop, solid ground return, thermal copper, and
correct inductor/capacitor current ratings.

## Pico Connections

| Pico pin | PCB net |
| --- | --- |
| VSYS/5V | Always-on 5V from power input |
| GND | Common ground |
| GP15 | Power switch enable |
| GP14 | Momentary download/pairing button |
| GP4 | DS3231 SDA |
| GP5 | DS3231 SCL |
| GP0/TX | Orange Pi UART RX |
| GP1/RX | Orange Pi UART TX |
| GP13 | Optional Orange Pi ready/shutdown GPIO |
| GP25 or spare GPIO | Optional button LED output |

## Orange Pi Connections

Use labelled board-to-wire terminals or headers for:

| PCB net | Orange Pi function |
| --- | --- |
| OPI_5V_SW | Orange Pi 5V input |
| OPI_GND | Orange Pi ground |
| OPI_3V3 | Orange Pi 3.3V logic rail |
| OPI_SDA | Enabled I2C SDA |
| OPI_SCL | Enabled I2C SCL |
| OPI_UART_TX | Orange Pi TX to Pico RX |
| OPI_UART_RX | Orange Pi RX from Pico TX |
| OPI_1WIRE | DS18B20 data GPIO |
| OPI_READY | Optional shutdown/ready GPIO to Pico GP13 |

## Sensor / ADC Connections

Use two ADS1115 modules or footprints.

ADS1115 #1:

| ADS1115 channel | Sensor |
| --- | --- |
| A0 | pH analog output |
| A1 | TDS analog output |
| A2 | Turbidity analog output |
| A3 | ORP analog output |

ADS1115 #2:

| ADS1115 channel | Sensor |
| --- | --- |
| A0 | Dissolved oxygen analog output |
| A1 | Ammonium ISE amplifier analog output |
| A2 | Spare |
| A3 | Spare |

Address setup:

| Module | ADDR connection | Address |
| --- | --- | --- |
| ADS1115 #1 | GND | `0x48` |
| ADS1115 #2 | VDD/3.3V | `0x49` |

Add silk labels beside every analog input. Sensor modules should connect by
screw terminals or locking connectors.

Important:

- ADS1115 VDD is 3.3V.
- Analog inputs must stay between 0V and 3.3V.
- Add optional divider footprints on each analog input for sensors that output
  up to 5V.
- Keep analog traces away from the MOSFET/load-switch power path.
- Add GND beside every sensor signal terminal.

## DS18B20 / BME280 / RTC

DS18B20:

- DATA to Orange Pi 1-Wire GPIO.
- 4.7k resistor from DATA to 3.3V.
- Connector pins: 3.3V, DATA, GND.

BME280:

- 3.3V, GND, SDA, SCL.
- Same I2C bus as ADS1115 modules.

DS3231:

- Connected to Pico I2C, not Orange Pi I2C.
- Pins: Pico 3V3, GND, GP4 SDA, GP5 SCL.

## Button / LED

Momentary button:

- `NO` to Pico GP14.
- `C` to GND.
- Leave `NC` unused.

Illuminated button LED:

- Use a spare Pico GPIO only if the LED is 3.3V compatible.
- Add series resistor footprint, for example 330 ohm.
- If the button LED is 5V/12V/24V type, use a transistor driver or leave the
  built-in LED disconnected.

## Recommended PCB Manufacturing Settings

For a service like PCBWay, use conservative rules instead of minimum rules:

- 2-layer PCB for revision 1.
- FR-4, 1.6mm thickness.
- 1oz copper minimum; 2oz copper preferred if switching Orange Pi power on board.
- HASL lead-free or ENIG finish.
- Minimum signal trace/space: 0.20mm or larger.
- Use wide pours/tracks for 5V and GND power.
- Finished drill holes matched to chosen terminals/headers.
- Large silkscreen labels on every connector.

PCBWay lists standard PCB capability down to very small trace/space values, but
they also recommend staying above about 6mil/0.15mm where possible to save cost
and improve yield. This design does not need fine-pitch routing, so use larger
rules.

Source: PCBWay capabilities page, https://www.pcbway.com/capabilities.html

## Board-Level Protection

Add these if space allows:

- Input fuse or resettable polyfuse.
- TVS diode on 5V input.
- Reverse-polarity protection for screw-terminal power input.
- Bulk capacitor near Orange Pi switched 5V output, for example 470uF-1000uF.
- 100nF decoupling near each module header.
- Optional I2C pull-up resistor footprints, marked DNP if modules already have pull-ups.
- Test pads for all power rails and communication lines.

## First Revision Scope

Revision 1 should prioritize reliability and debug access:

- Use through-hole headers/screw terminals.
- Use module sockets for Pico, RTC, ADS1115 boards, and BME280.
- Keep the Orange Pi connected by labelled cable/header rather than fixed SBC
  mounting.
- Include mounting holes.
- Include large connector labels.
- Include spare ADC channels and spare GPIO pads.

Do not integrate the EC25 modem on this PCB in revision 1. Keep the modem on its
own USB/Mini PCIe/M.2 carrier and power it from the Orange Pi side. Cellular
modems have burst current, RF layout, antenna, SIM, and certification concerns
that are better handled by an existing modem carrier.

## Open Decisions Before Final PCB Routing

Confirm these before ordering the board:

- Exact Orange Pi board for the first physical footprint. The current PCB draft
  targets the Zero 3 header.
- Exact CH224K package and pin mapping from the supplier datasheet.
- Exact TPS54531DDA layout values and footprint against the TI datasheet.
- Exact MOSFET/load-switch part.
- Exact connector type: screw terminal, JST-XH, JST-PH, Dupont header, or mixed.
- Whether sensor modules are powered by switched 5V, always-on 5V, or Orange Pi 3.3V.
- Whether the button LED is 3.3V compatible.
- Enclosure size and mounting-hole locations.
- Whether PCB should carry high-current 5V directly or only control an external
  load-switch module.
- KiCad PCB routing. Current DRC has zero violations but still reports
  unconnected items because the PCB is a placement/net-assignment draft.

## Deliverables Needed for PCBWay

Once laid out in KiCad, export:

- Gerber files.
- Drill files.
- Board outline.
- Pick/place file only if using PCB assembly.
- BOM only if using PCB assembly.
- Schematic PDF for review.
- PCB render/top-bottom images for checking connector labels.

Do not order until the schematic, net labels, and connector pinout have been
reviewed against the actual Orange Pi, Pico, sensor modules, and switch module
on the bench.

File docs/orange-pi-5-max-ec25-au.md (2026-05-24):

# Orange Pi 5 Max + Quectel EC25-AU Variant

This branch targets an Orange Pi 5 Max with a Quectel EC25-AU cellular modem.

## Compact M.2 modem build

You can absolutely make this compact, but use the right kind of M.2/carrier connection.

The Orange Pi 5 Max onboard M.2 slot is an M-key PCIe storage slot for NVMe/SATA SSDs. Do not plug a cellular modem into that slot.

For the EC25-AU, use one of these compact options:

| Modem form | Compact carrier to search for | Connects to Orange Pi as |
| --- | --- | --- |
| EC25-AU Mini PCIe | `Mini PCIe LTE modem USB adapter` or `Mini PCIe WWAN USB carrier` | USB |
| M.2 B-key LTE modem | `M.2 B key LTE modem USB adapter` or `M.2 B key WWAN USB carrier` | USB |
| Bare EC25-AU LGA module | Custom carrier board only | USB/UART from carrier |

Many EC25-AU listings are Mini PCIe, not M.2. If your listing really says M.2, check the key notch and pinout before buying the carrier.

The compact carrier should provide:

- USB 2.0 data connection to the Orange Pi.
- SIM card slot.
- Main LTE antenna connector.
- Stable modem power supply.
- Optional GNSS antenna connector if your module supports GPS/GNSS.

On Linux the modem should appear as several `/dev/ttyUSB*` ports after the correct USB serial drivers bind. The AT command port is commonly `/dev/ttyUSB2`, but confirm on your board.

Recommended search terms:

```text
EC25-AU Mini PCIe USB adapter SIM antenna
Mini PCIe LTE modem USB carrier board SIM
M.2 B key LTE modem USB adapter SIM
M.2 WWAN USB adapter Quectel SIM antenna
Quectel EC25 USB carrier board
```

Avoid:

```text
M.2 M-key NVMe adapter
M.2 SSD adapter
PCIe NVMe riser
```

Those are for storage, not LTE modems.

## What changes in this branch

- `I2C_BUS_NUMBER` is configurable by environment variable, but the logger now auto-detects likely Orange Pi I2C buses when it is not set.
- `PICO_SERIAL_PORT` remains configurable by environment variable.
- `cellular_uploader.py` can check EC25-AU status with AT commands.
- `orange_pi_boot_wrapper.py` can optionally upload the newest weekly CSV before shutdown.
- `alert_manager.py` evaluates freshwater safety alerts, barometric pressure drops, water temperature changes, and daily status messages.

## Suggested Orange Pi 5 Max setup

Enable the I2C and UART overlays for the 40-pin header using the Orange Pi configuration tool or the official image overlay method.

Then find the actual bus names:

```bash
ls /dev/i2c-*
ls /dev/ttyS*
```

Scan for the two ADS1115 boards:

```bash
sudo i2cdetect -y 3
sudo i2cdetect -y 4
sudo i2cdetect -y 5
sudo i2cdetect -y 8
```

Use whichever bus shows `0x48` and `0x49`.

Example environment for an Orange Pi 5 Max install:

```bash
export I2C_BUS_NUMBER=5
export PICO_SERIAL_PORT=/dev/ttyS4
export EC25_AT_PORT=/dev/ttyUSB2
```

`I2C_BUS_NUMBER` is optional. Leave it unset first; set it only if the enabled header bus is known and auto-detection does not find the ADS1115/BME280 modules.

If your enabled header UART appears as another device, change `PICO_SERIAL_PORT`.

## EC25-AU modem check

Install the required packages:

```bash
sudo apt update
sudo apt install -y curl python3-serial modemmanager usb-modeswitch
```

Check that the modem appears:

```bash
lsusb
ls /dev/ttyUSB*
```

Check AT command status:

```bash
python3 cellular_uploader.py --status
```

Expected useful responses include:

```text
AT: OK
AT+CPIN?: READY
AT+CSQ: signal quality
AT+COPS?: network/operator
AT+QNWINFO: radio access technology and band
```

For server updates, the Orange Pi also needs an active data connection. One common approach is NetworkManager/ModemManager:

```bash
sudo mmcli -L
sudo nmcli c add type gsm ifname "*" con-name ec25 apn your.apn.here
sudo nmcli c up ec25
```

Use the APN from your SIM provider. SMS alerts can work over the modem AT port even when no HTTP upload URL is configured.

## Optional cellular upload

The logger still records to weekly CSV files first. Cellular upload is optional and disabled by default.

To upload the newest weekly CSV after each boot-time reading:

```bash
export CELLULAR_UPLOAD_ENABLED=1
export CELLULAR_UPLOAD_URL=https://your-server.example/upload
```

Then the boot wrapper will:

1. Take one reading.
2. Save it to the current weekly CSV.
3. Run `cellular_uploader.py --upload-latest`.
4. Shut the Orange Pi down.

If no upload URL is set, the uploader exits without blocking normal logging.

## SMS and server status reporting

This branch can send:

- A JSON status update to your server after each reading.
- A daily SMS status message on the first log of the day after 4am local time.
- SMS alerts when freshwater readings look unsafe.
- SMS alerts for barometric pressure drops.
- SMS alerts for water temperature changes compared with the recent average.

Enable reporting:

```bash
export CELLULAR_REPORTING_ENABLED=1
export CELLULAR_STATUS_URL=https://your-server.example/water-logger/status
export ALERT_SMS_NUMBERS=+61400111222,+61400999888
```

SMS is optional. If there is no EC25 AT port, no SIM, the SIM is PIN-locked, `pyserial` is missing, or `CELLULAR_SMS_ENABLED=0`, SMS sending is skipped before any alert texts are attempted.

```bash
export CELLULAR_SMS_ENABLED=auto  # default: send only when modem and SIM are ready
export CELLULAR_SMS_ENABLED=0     # force SMS off
```

`ALERT_SMS_NUMBERS` is optional. If it is not set, the phone app can save alert numbers to:

```text
records/cellular_config.json
```

From the Android app, use:

```text
Get SMS Numbers
Save SMS Numbers
Signal Status
Test SMS
```

From a Bluetooth terminal:

```text
sms
setsms +61400111222,+61400999888
clearsms
resetbaseline
signal
testsms
```

To clear saved SMS recipients:

```text
clearsms
```

If `ALERT_SMS_NUMBERS` is set in the environment, it takes priority over the saved phone-app config.

Run manually for testing:

```bash
python3 cellular_uploader.py --report
```

The server receives JSON containing:

```text
generated_at
latest
summary
alerts
sms_alerts
daily_status_due
record_count_window
```

If `CELLULAR_STATUS_URL` is not set, server updates are skipped. If `ALERT_SMS_NUMBERS` is not set, or no configured phone-app numbers exist, SMS is skipped.

## Freshwater alert defaults

These are starter alert thresholds, not legal or scientific certification. Tune them for your creek and calibrate every probe.

| Environment variable | Default | Alert meaning |
| --- | ---: | --- |
| `ALERT_PH_MIN` | `6.5` | pH below this alerts |
| `ALERT_PH_MAX` | `9.0` | pH above this alerts |
| `ALERT_DO_MIN_MG_L` | `5.0` | dissolved oxygen below this alerts |
| `ALERT_NH3_MAX_MG_L` | `0.05` | toxic ammonia NH3 at/above this alerts |
| `ALERT_WATER_TEMP_MIN_C` | `5.0` | water temp below this alerts |
| `ALERT_WATER_TEMP_MAX_C` | `30.0` | water temp above this alerts |
| `ALERT_TURBIDITY_MAX_NTU` | `50.0` | turbidity above this alerts |
| `ALERT_TDS_MAX_PPM` | `1000.0` | TDS above this alerts |
| `ALERT_PRESSURE_DROP_HPA_24H` | `6.0` | pressure drop over recent 24h alerts |
| `ALERT_TEMP_CHANGE_C_24H` | `2.0` | water temp change versus recent 24h average alerts |
| `ALERT_COOLDOWN_SECONDS` | `21600` | same alert SMS cooldown, default 6 hours |
| `DAILY_STATUS_AFTER_HOUR` | `4` | daily status waits until the first log at or after this local hour |
| `ALERT_TIMEZONE` | `Australia/Brisbane` | local timezone used for the daily status cutoff |

Sensor communication failures can generate warning alerts, but only for sensors that were working in the initial baseline. The baseline is built from the first recent rows that report each sensor as `ok`, then finalized and saved so later reports do not repeatedly rebuild it. This avoids nuisance alerts for optional sensors that were never installed.

The alert manager saves the sensor baseline in:

```text
records/cellular_alert_state.json
```

If a sensor never reports `ok` while the baseline is built, later failures for that sensor will not trigger SMS alerts until the records/state are cleared and a new baseline is created. To reset the baseline from the phone, send:

```text
resetbaseline
```

You can also delete:

```text
records/cellular_alert_state.json
```

Then let the logger take new readings with the sensors you want monitored.

## EC25-AU SMS notes

SMS is sent through AT commands on `EC25_AT_PORT`, usually `/dev/ttyUSB2`.

The helper uses:

```text
AT
AT+CMGF=1
AT+CMGS="+614..."
```

Make sure the SIM can send SMS, the antenna is attached, and the modem has network signal. Check with:

```bash
python3 cellular_uploader.py --status
```

If SMS fails, the logger still keeps the CSV data. Reporting failures do not delete readings.

## Signal status

The recorder can report modem signal over Bluetooth or the Android app:

```text
signal
```

The response includes:

```text
Network: 4G
Cell signal: 74% (-67 dBm)
CSQ: 23
Operator: ...
Radio info: ...
```

`Network` is shown as `2G`, `3G`, `4G`, `no signal`, or `signal, network type unknown`, based on EC25 `AT+QNWINFO` and `AT+CSQ` responses.

To send a test SMS to the configured alert recipients:

```text
testsms
```

## Power notes

The Orange Pi 5 Max uses more power than the Zero 3. Use a larger power bank or battery pack, and make sure the 5V relay/MOS switch can handle the startup current.

The EC25-AU can draw burst current during LTE transmit. Use a modem carrier board with stable power and a good antenna. For a compact enclosure, keep the antenna outside or against a non-metallic window in the case; do not bury the antenna behind metal or next to noisy power wiring.

## Main branch status

These Orange Pi 5 Max and optional EC25-AU changes are now merged into `main`. The same codebase supports the Zero 3 without a cellular modem and skips SMS automatically when no modem/SIM is ready.

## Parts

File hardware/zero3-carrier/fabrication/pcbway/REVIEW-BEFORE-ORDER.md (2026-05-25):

# Review Required Before Ordering

These Gerbers are an R1 draft produced by an automated workflow:

1. `generate_schematic.py` -> schematic + symbol library + pinout CSV
2. `generate_pcb.py` -> placement + dual-layer GND copper pours
3. `route_with_freerouting.py` -> Freerouting auto-routing of all 83 remaining
   signal/power nets

Validation that passed before export:

- `kicad-cli sch erc`: 0 violations
- `kicad-cli pcb drc --refill-zones`: 0 violations, 0 unconnected items

## Manual review items before clicking "Order"

1. **TPS54531 buck regulator layout.** The auto-router produced electrically
   correct traces but does not follow the TI reference layout. For a 5A buck
   supply this is the difference between "regulates well, low EMI" and
   "marginal, noisy, may not meet load". Re-route by hand in KiCad:
   - Short SW node loop between U2 pin PH, L1, D2, and CBOOT.
   - Tight CIN1/CIN2/CIN3 placement right at U2 VIN/GND.
   - Tight COUT1/COUT2 placement at L1 output.
   - Solid GND under U2 PowerPAD (EP) with thermal vias to the bottom pour.
   - Keep BUCK_FB away from BUCK_SW.

2. **AO4407A high-side switch layout.** Wide copper between FUSED_5V1 ->
   Q1 source pads and Q1 drain pads -> C1 -> OPI_5V_SW. Keep PWR_GATE
   short and away from BUCK_SW.

3. **CH224K PD sink pinout.** The schematic uses a placeholder pin map
   ("CH224K package pinouts vary between supplier drawings"). Confirm
   against the supplier datasheet of the actual part you order.

4. **Footprint matching.** Spot-check each footprint against the part you
   plan to assemble:
   - J14 USB-C receptacle (16-pin HRO TYPE-C-31-M-12)
   - U2 TPS54531DDA SOIC PowerPAD
   - Q1 AO4407A SOIC-8
   - L1 4.7uH inductor footprint
   - Terminal blocks (Phoenix MKDS-1.5-3-5.08 pitch)

5. **Visual Gerber inspection.** Open the Gerbers in an independent viewer
   (PCBWay's online previewer or `gerbv`) and check:
   - Board outline matches your enclosure.
   - Drill positions match pad positions.
   - Silkscreen labels are present beside every external connector.
   - No copper outside the board outline.
   - Solder mask openings match pads.

6. **Bench prototype first.** Order one or two boards, assemble them on
   the bench, and verify the buck regulator regulates at 5.1V under load
   before placing a quantity order.

## Auto-routing notes

Freerouting was invoked at `medium` effort (max 20 passes). Auto-router
output is deterministic given the same DSN input, so you can re-run
`python ../route_with_freerouting.py` to reproduce these Gerbers, or
`--effort thorough` for more optimization passes.

## File list

- `zero3-water-logger-carrier-F_Cu.gtl` - top copper
- `zero3-water-logger-carrier-B_Cu.gbl` - bottom copper
- `zero3-water-logger-carrier-F_Mask.gts` / `-B_Mask.gbs` - solder mask
- `zero3-water-logger-carrier-F_Silkscreen.gto` / `-B_Silkscreen.gbo` - silkscreen
- `zero3-water-logger-carrier-Edge_Cuts.gm1` - board outline
- `zero3-water-logger-carrier-job.gbrjob` - Gerber job file
- `zero3-water-logger-carrier.drl` - plated through-holes (Excellon)
- `zero3-water-logger-carrier-drl_map.pdf` - drill map (human reference)
- `zero3-water-logger-carrier-drill.rpt` - drill report
- `schematic.pdf` - schematic for cross-checking

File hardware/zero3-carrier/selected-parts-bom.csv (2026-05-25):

Ref | Qty | Selected part / value | Footprint target | Purpose | Notes
J14 | 1 | USB-C 16-pin receptacle such as HRO TYPE-C-31-M-12 | USB_C_Receptacle_USB2.0_16P | USB-C PD input | Use a mechanically reinforced connector footprint and verify shell pad geometry
U1 | 1 | CH224K | ESSOP-10 / SOP-10 | USB-C PD sink controller | Strap for fixed 9V request for revision 1
D1 | 1 | USB VBUS TVS diode rated for PD voltage | SMA/SMB or compact TVS footprint | Input surge/ESD protection | Choose standoff voltage suitable for negotiated PD rail
F1 | 1 | Resettable fuse 3A-5A hold | SMD polyfuse | Input protection | Size from expected total current and enclosure temperature
U2 | 1 | TPS54531DDA | SO-PowerPAD-8 | 5A buck regulator | Use TI datasheet/reference layout closely
L1 | 1 | 4.7uH shielded inductor rated >=6A | Power inductor footprint | Buck output inductor | Start from TI typical 5V/5A application value
D2 | 1 | CDBC540-G or 5A/40V Schottky | SMA/SMB power diode | Buck catch diode | Required for TPS54531 non-synchronous buck
CIN1 | 1 | 4.7uF 50V X7R | 1206/1210 | Buck input capacitor | Place close to U2 VIN/GND
CIN2 | 1 | 4.7uF 50V X7R | 1206/1210 | Buck input capacitor | Place close to U2 VIN/GND
CIN3 | 1 | 10nF 50V X7R | 0603/0805 | High-frequency VIN bypass | Place close to U2
CBOOT | 1 | 100nF 25V X7R | 0603/0805 | Bootstrap capacitor | Between TPS54531 BOOT and PH/SW pins
CSS | 1 | 10nF | 0603/0805 | Slow-start capacitor | TPS54531 SS pin
COUT1 | 1 | 47uF 10V low-ESR | 1210 or polymer | Buck output capacitor | Place near L1 output/GND
COUT2 | 1 | 47uF 10V low-ESR | 1210 or polymer | Buck output capacitor | Place near L1 output/GND
C1 | 1 | 470uF-1000uF 10V low-ESR electrolytic/polymer | Radial or SMD bulk | Switched 5V bulk storage | Near Orange Pi switched 5V output
RFB1 | 1 | 10.2k 1% | 0603/0805 | TPS54531 feedback upper resistor | TI typical example for about 5V output
RFB2 | 1 | 1.96k 1% | 0603/0805 | TPS54531 feedback lower resistor | TI typical example for about 5V output
RCOMP1 | 1 | 37.4k 1% | 0603/0805 | TPS54531 compensation resistor | TI typical example
CCOMP1 | 1 | 2200pF | 0603/0805 | TPS54531 compensation capacitor | TI typical example
CCOMP2 | 1 | 22pF | 0603/0805 | TPS54531 compensation capacitor | TI typical example
REN1 | 1 | 665k 1% | 0603/0805 | TPS54531 UVLO upper resistor | TI typical example for 8V minimum design
REN2 | 1 | 130k 1% | 0603/0805 | TPS54531 UVLO lower resistor | TI typical example for 8V minimum design
Q1 | 1 | AO4407A | SOIC-8 / SOP-8 | High-side P-channel MOSFET | 30V P-channel MOSFET suitable for 5V rail switching
Q2 | 1 | 2N7002 | SOT-23 | Gate-driver N-MOSFET | Pulls Q1 gate low when Pico GP15 is high
R2 | 1 | 100k | 0603/0805 | Q1 gate pull-up | Pulls P-channel gate to 5.1V so Orange Pi defaults off
R3 | 1 | 1k | 0603/0805 | Q2 gate resistor | Between Pico GP15 and Q2 gate
R4 | 1 | 100k | 0603/0805 | Q2 gate pulldown | Keeps Q2 off while Pico boots
J15 | 1 | 1x04 2.54mm header or screw terminal | Connector header/button terminal | Download button contacts and optional LED | Wire NO/C for button and LED+/LED- only if LED voltage is compatible
R5 | 1 | 330 ohm if using bare 3.3V LED | 0603/0805 | Optional button LED current limit | Only fit if firmware drives a spare Pico GPIO for the button LED
J16 | 1 | 1x04 2.54mm header | Connector header | Spare ADS1115 #2 A2/A3 analog input breakout | Optional field expansion
TP1 | 1 | Test pad | 1.5mm test pad | USB VBUS test
TP2 | 1 | Test pad | 1.5mm test pad | PD negotiated rail test
TP3 | 1 | Test pad | 1.5mm test pad | Regulated 5.1V test
TP4 | 1 | Test pad | 1.5mm test pad | Switched 5V test
TP5 | 1 | Test pad | 1.5mm test pad | GND test

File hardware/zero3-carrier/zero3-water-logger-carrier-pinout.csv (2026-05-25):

Ref | Pin | Pin name | Net | Notes
J14 | A4/B4/A9/B9 | VBUS | USB_VBUS | USB-C PD input receptacle
J14 | A1/B1/A12/B12 | GND | GND | USB-C PD input receptacle
J14 | A5 | CC1 | USB_CC1 | USB-C PD input receptacle
J14 | B5 | CC2 | USB_CC2 | USB-C PD input receptacle
J14 | SH | SHIELD | GND | USB-C PD input receptacle
D1 | 1 | K | USB_VBUS | VBUS TVS
D1 | 2 | A | GND | VBUS TVS
U1 | VBUS | VBUS | USB_VBUS | CH224K PD sink 9V
U1 | CC1 | CC1 | USB_CC1 | CH224K PD sink 9V
U1 | CC2 | CC2 | USB_CC2 | CH224K PD sink 9V
U1 | GND | GND | GND | CH224K PD sink 9V
U1 | VOUT | VOUT | PD_NEGOTIATED_VBUS | CH224K PD sink 9V
U1 | CFG1 | CFG1 | PD_CFG | CH224K PD sink 9V
U1 | CFG2 | CFG2 | PD_CFG | CH224K PD sink 9V
U1 | CFG3 | CFG3 | PD_CFG | CH224K PD sink 9V
F1 | 1 | IN | PD_NEGOTIATED_VBUS | 3A-5A polyfuse
F1 | 2 | OUT | PD_FUSED | 3A-5A polyfuse
U2 | VIN | VIN | PD_FUSED | TPS54531DDA 5A buck
U2 | GND | GND | GND | TPS54531DDA 5A buck
U2 | PH | PH/SW | BUCK_SW | TPS54531DDA 5A buck
U2 | BOOT | BOOT | BUCK_BOOT | TPS54531DDA 5A buck
U2 | VSENSE | FB | BUCK_FB | TPS54531DDA 5A buck
U2 | COMP | COMP | BUCK_COMP | TPS54531DDA 5A buck
U2 | SS | SS | BUCK_SS | TPS54531DDA 5A buck
U2 | EN | EN | BUCK_EN | TPS54531DDA 5A buck
U2 | PAD | EP | GND | TPS54531DDA 5A buck
L1 | 1 | SW | BUCK_SW | 4.7uH >=6A
L1 | 2 | OUT | FUSED_5V1 | 4.7uH >=6A
D2 | K | K | BUCK_SW | 5A 40V Schottky
D2 | A | A | GND | 5A 40V Schottky
CIN1 | 1 | + | PD_FUSED | 4.7uF 50V
CIN1 | 2 | - | GND | 4.7uF 50V
CIN2 | 1 | + | PD_FUSED | 4.7uF 50V
CIN2 | 2 | - | GND | 4.7uF 50V
CBOOT | 1 | BOOT | BUCK_BOOT | 100nF
CBOOT | 2 | SW | BUCK_SW | 100nF
CSS | 1 | SS | BUCK_SS | 10nF
CSS | 2 | GND | GND | 10nF
REN1 | 1 | VIN | PD_FUSED | 665k
REN1 | 2 | EN | BUCK_EN | 665k
REN2 | 1 | EN | BUCK_EN | 130k
REN2 | 2 | GND | GND | 130k
RCOMP1 | 1 | COMP | BUCK_COMP | 37.4k
RCOMP1 | 2 | NODE | BUCK_COMP_RC | 37.4k
CCOMP1 | 1 | NODE | BUCK_COMP_RC | 2200pF
CCOMP1 | 2 | GND | GND | 2200pF
CCOMP2 | 1 | COMP | BUCK_COMP | 22pF
CCOMP2 | 2 | GND | GND | 22pF
CIN3 | 1 | + | PD_FUSED | 10nF 50V
CIN3 | 2 | - | GND | 10nF 50V
COUT1 | 1 | + | FUSED_5V1 | 47uF 10V
COUT1 | 2 | - | GND | 47uF 10V
COUT2 | 1 | + | FUSED_5V1 | 47uF 10V
COUT2 | 2 | - | GND | 47uF 10V
RFB1 | 1 | TOP | FUSED_5V1 | 10.2k 1%
RFB1 | 2 | FB | BUCK_FB | 10.2k 1%
RFB2 | 1 | FB | BUCK_FB | 1.96k 1%
RFB2 | 2 | GND | GND | 1.96k 1%
Q1 | S | SOURCE | FUSED_5V1 | AO4407A P-MOS high-side
Q1 | D | DRAIN | OPI_5V_SW | AO4407A P-MOS high-side
Q1 | G | GATE | PWR_GATE | AO4407A P-MOS high-side
Q2 | D | DRAIN | PWR_GATE | 2N7002
Q2 | S | SOURCE | GND | 2N7002
Q2 | G | GATE | Q2_GATE | 2N7002
R2 | 1 | 5V1 | FUSED_5V1 | 100k
R2 | 2 | GATE | PWR_GATE | 100k
R3 | 1 | PICO | PICO_GP15 | 1k
R3 | 2 | Q2G | Q2_GATE | 1k
R4 | 1 | Q2G | Q2_GATE | 100k
R4 | 2 | GND | GND | 100k
C1 | 1 | + | OPI_5V_SW | 470uF-1000uF 10V
C1 | 2 | - | GND | 470uF-1000uF 10V
J1 | 1 | 3V3 | OPI_3V3 | Orange Pi Zero 3 26-pin header (physical pin numbering)
J1 | 2 | 5V | OPI_5V_SW | Orange Pi Zero 3 26-pin header (physical pin numbering)
J1 | 3 | SDA | OPI_SDA | Orange Pi Zero 3 26-pin header (physical pin numbering)
J1 | 4 | 5V | OPI_5V_SW | Orange Pi Zero 3 26-pin header (physical pin numbering)
J1 | 5 | SCL | OPI_SCL | Orange Pi Zero 3 26-pin header (physical pin numbering)
J1 | 6 | GND | GND | Orange Pi Zero 3 26-pin header (physical pin numbering)
J1 | 7 | 1WIRE | OPI_1WIRE | Orange Pi Zero 3 26-pin header (physical pin numbering)
J1 | 8 | TX | UART_OPI_TX_PICO_RX | Orange Pi Zero 3 26-pin header (physical pin numbering)
J1 | 9 | GND | GND | Orange Pi Zero 3 26-pin header (physical pin numbering)
J1 | 10 | RX | UART_PICO_TX_OPI_RX | Orange Pi Zero 3 26-pin header (physical pin numbering)
J1 | 11 | READY | OPI_READY | Orange Pi Zero 3 26-pin header (physical pin numbering)
J1 | 14 | GND | GND | Orange Pi Zero 3 26-pin header (physical pin numbering)
J1 | 17 | 3V3 | OPI_3V3 | Orange Pi Zero 3 26-pin header (physical pin numbering)
J1 | 20 | GND | GND | Orange Pi Zero 3 26-pin header (physical pin numbering)
J1 | 25 | GND | GND | Orange Pi Zero 3 26-pin header (physical pin numbering)
J2 | 1 | GP0/TX | UART_PICO_TX_OPI_RX | Raspberry Pi Pico 2x20 header (physical pin numbering)
J2 | 2 | GP1/RX | UART_OPI_TX_PICO_RX | Raspberry Pi Pico 2x20 header (physical pin numbering)
J2 | 3 | GND | GND | Raspberry Pi Pico 2x20 header (physical pin numbering)
J2 | 6 | GP4 | PICO_GP4 | Raspberry Pi Pico 2x20 header (physical pin numbering)
J2 | 7 | GP5 | PICO_GP5 | Raspberry Pi Pico 2x20 header (physical pin numbering)
J2 | 8 | GND | GND | Raspberry Pi Pico 2x20 header (physical pin numbering)
J2 | 13 | GND | GND | Raspberry Pi Pico 2x20 header (physical pin numbering)
J2 | 17 | GP13 | OPI_READY | Raspberry Pi Pico 2x20 header (physical pin numbering)
J2 | 18 | GND | GND | Raspberry Pi Pico 2x20 header (physical pin numbering)
J2 | 19 | GP14 | PICO_GP14 | Raspberry Pi Pico 2x20 header (physical pin numbering)
J2 | 20 | GP15 | PICO_GP15 | Raspberry Pi Pico 2x20 header (physical pin numbering)
J2 | 21 | GP16/LED | PICO_LED_GP16 | Raspberry Pi Pico 2x20 header (physical pin numbering)
J2 | 23 | GND | GND | Raspberry Pi Pico 2x20 header (physical pin numbering)
J2 | 28 | GND | GND | Raspberry Pi Pico 2x20 header (physical pin numbering)
J2 | 33 | GND | GND | Raspberry Pi Pico 2x20 header (physical pin numbering)
J2 | 36 | 3V3 | PICO_3V3 | Raspberry Pi Pico 2x20 header (physical pin numbering)
J2 | 38 | GND | GND | Raspberry Pi Pico 2x20 header (physical pin numbering)
J2 | 39 | VSYS | FUSED_5V1 | Raspberry Pi Pico 2x20 header (physical pin numbering)
J3 | 1 | VDD | OPI_3V3 | ADS1115 #1 module header | address 0x48 (ADDR -> GND)
J3 | 2 | GND | GND | ADS1115 #1 module header | address 0x48 (ADDR -> GND)
J3 | 3 | SDA | OPI_SDA | ADS1115 #1 module header | address 0x48 (ADDR -> GND)
J3 | 4 | SCL | OPI_SCL | ADS1115 #1 module header | address 0x48 (ADDR -> GND)
J3 | 5 | ADDR | GND | ADS1115 #1 module header | address 0x48 (ADDR -> GND)
J3 | 6 | A0 | PH_AIN | ADS1115 #1 module header | address 0x48 (ADDR -> GND)
J3 | 7 | A1 | TDS_AIN | ADS1115 #1 module header | address 0x48 (ADDR -> GND)
J3 | 8 | A2 | TURB_AIN | ADS1115 #1 module header | address 0x48 (ADDR -> GND)
J3 | 9 | A3 | ORP_AIN | ADS1115 #1 module header | address 0x48 (ADDR -> GND)
J4 | 1 | VDD | OPI_3V3 | ADS1115 #2 module header | address 0x49 (ADDR -> 3.3V)
J4 | 2 | GND | GND | ADS1115 #2 module header | address 0x49 (ADDR -> 3.3V)
J4 | 3 | SDA | OPI_SDA | ADS1115 #2 module header | address 0x49 (ADDR -> 3.3V)
J4 | 4 | SCL | OPI_SCL | ADS1115 #2 module header | address 0x49 (ADDR -> 3.3V)
J4 | 5 | ADDR | OPI_3V3 | ADS1115 #2 module header | address 0x49 (ADDR -> 3.3V)
J4 | 6 | A0 | DO_AIN | ADS1115 #2 module header | address 0x49 (ADDR -> 3.3V)
J4 | 7 | A1 | NH4_AIN | ADS1115 #2 module header | address 0x49 (ADDR -> 3.3V)
J4 | 8 | A2 | SPARE_AIN2 | ADS1115 #2 module header | address 0x49 (ADDR -> 3.3V)
J4 | 9 | A3 | SPARE_AIN3 | ADS1115 #2 module header | address 0x49 (ADDR -> 3.3V)
J5 | 1 | VCC | OPI_3V3 | DS18B20 waterproof temperature probe
J5 | 2 | DATA | OPI_1WIRE | DS18B20 waterproof temperature probe
J5 | 3 | GND | GND | DS18B20 waterproof temperature probe
R1 | 1 | 3V3 | OPI_3V3 | 4.7k
R1 | 2 | DATA | OPI_1WIRE | 4.7k
J6 | 1 | VCC | OPI_3V3 | BME280 ambient air sensor (I2C)
J6 | 2 | GND | GND | BME280 ambient air sensor (I2C)
J6 | 3 | SDA | OPI_SDA | BME280 ambient air sensor (I2C)
J6 | 4 | SCL | OPI_SCL | BME280 ambient air sensor (I2C)
J7 | 1 | VCC | PICO_3V3 | DS3231 RTC (Pico I2C bus | separate from Orange Pi)
J7 | 2 | GND | GND | DS3231 RTC (Pico I2C bus | separate from Orange Pi)
J7 | 3 | SDA | PICO_GP4 | DS3231 RTC (Pico I2C bus | separate from Orange Pi)
J7 | 4 | SCL | PICO_GP5 | DS3231 RTC (Pico I2C bus | separate from Orange Pi)
J15 | 1 | NO | PICO_GP14 | Download/pairing button (NO/C) and optional LED
J15 | 2 | C | GND | Download/pairing button (NO/C) and optional LED
J15 | 3 | LED+ | BUTTON_LED_A | Download/pairing button (NO/C) and optional LED
J15 | 4 | LED- | GND | Download/pairing button (NO/C) and optional LED
R5 | 1 | PICO | PICO_LED_GP16 | 330R if 3.3V LED
R5 | 2 | LED+ | BUTTON_LED_A | 330R if 3.3V LED
J16 | 1 | 3V3 | OPI_3V3 | Spare ADS1115 #2 A2/A3 analog header
J16 | 2 | GND | GND | Spare ADS1115 #2 A2/A3 analog header
J16 | 3 | AIN2 | SPARE_AIN2 | Spare ADS1115 #2 A2/A3 analog header
J16 | 4 | AIN3 | SPARE_AIN3 | Spare ADS1115 #2 A2/A3 analog header
J8 | 1 | 5V | OPI_5V_SW | pH sensor module terminal
J8 | 2 | GND | GND | pH sensor module terminal
J8 | 3 | AO | PH_AIN | pH sensor module terminal
J9 | 1 | 5V | OPI_5V_SW | TDS sensor module terminal
J9 | 2 | GND | GND | TDS sensor module terminal
J9 | 3 | AO | TDS_AIN | TDS sensor module terminal
J10 | 1 | 5V | OPI_5V_SW | Turbidity sensor module terminal
J10 | 2 | GND | GND | Turbidity sensor module terminal
J10 | 3 | AO | TURB_AIN | Turbidity sensor module terminal
J11 | 1 | 5V | OPI_5V_SW | ORP sensor module terminal
J11 | 2 | GND | GND | ORP sensor module terminal
J11 | 3 | AO | ORP_AIN | ORP sensor module terminal
J12 | 1 | 5V | OPI_5V_SW | Dissolved oxygen sensor module terminal
J12 | 2 | GND | GND | Dissolved oxygen sensor module terminal
J12 | 3 | AO | DO_AIN | Dissolved oxygen sensor module terminal
J13 | 1 | 5V | OPI_5V_SW | Ammonium ISE amplifier terminal
J13 | 2 | GND | GND | Ammonium ISE amplifier terminal
J13 | 3 | AO | NH4_AIN | Ammonium ISE amplifier terminal

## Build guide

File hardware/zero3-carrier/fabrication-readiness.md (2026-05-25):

# Fabrication Readiness

Status: **Gerbers exported and ready to inspect; do not order until the
switching power supply layout has been reviewed.**

ERC and DRC are clean. All 83 signal/power nets have been routed by
Freerouting on top of the schematic-synced placement. The Gerber upload
package is in `fabrication/pcbway/` and zipped as
`fabrication/zero3-water-logger-carrier-R1.zip`. The review checklist that
must be cleared before ordering is in `fabrication/pcbway/REVIEW-BEFORE-ORDER.md`.

## Current State

- Board outline, assigned footprints, and schematic nets exist.
- GND copper pour on both layers, solid pad connection (no thermal-relief
  starvation against tight USB-C SMD pads). The pour brings the pre-routing
  unconnected-pad count down from 136 to **83**.
- KiCad PCB DRC reports **zero violations**.
- KiCad schematic ERC passes.
- USB-C PD, buck regulator, and MOSFET switch parts are captured in the R1
  schematic draft.
- Pinout CSV is generated from the same `COMPONENTS` table the schematic
  uses, so the published pinout cannot drift from actual net assignments.
- `generate_pcb.py` can regenerate the current PCB placement/net-assignment
  draft from the same component plan as the schematic and resolves the KiCad
  footprint library on Windows, macOS, and Linux (honours
  `KICAD_FOOTPRINT_DIR`).
- `validate_design.py` bundles ERC + DRC + CSV format checks behind a single
  pre-commit gate.
- `route_with_freerouting.py` is a one-command auto-router workflow (exports
  DSN, fetches and runs Freerouting, imports SES, refills zones, re-runs DRC).
- `manual-routing-guide.md` walks the per-section routing if you prefer to
  route by hand in KiCad GUI.

## Required Before Gerber Upload

1. Review the R1 schematic draft against the selected part datasheets.
2. Verify CH224K strap pins for a fixed 9V PD request.
3. Verify TPS54531DDA support parts and values against the datasheet/reference
   design.
4. Verify all footprints in the schematic, especially USB-C, CH224K, TPS54531,
   AO4407A, and terminal blocks.
5. Complete PCB routing from the existing schematic-synced placement.
6. Route the PD/buck power section with wide copper and regulator datasheet
   layout rules.
7. Route all low-current control and sensor nets.
8. Run PCB DRC and schematic ERC with zero errors and zero unconnected items.
9. Open the generated Gerbers in a separate Gerber viewer and inspect:
    - board outline,
    - drill holes,
    - USB-C footprint,
    - regulator footprint,
    - MOSFET footprint,
    - connector labels,
    - mounting holes,
    - copper clearances,
    - polarity marks.

## Recommended Upload Package

Once the design is actually routed and passes checks, export:

- Front copper
- Back copper
- Front solder mask
- Back solder mask
- Front silkscreen
- Back silkscreen if used
- Edge cuts
- Excellon drill files
- Gerber job file
- Schematic PDF for review
- BOM and position files only if using PCB assembly

## KiCad CLI Export Commands

Run from the repository root:

```powershell
$kicad = "C:\Program Files\KiCad\10.0\bin\kicad-cli.exe"
$pcb = "hardware\zero3-carrier\zero3-water-logger-carrier.kicad_pcb"
$sch = "hardware\zero3-carrier\zero3-water-logger-carrier.kicad_sch"
$out = "hardware\zero3-carrier\fabrication\pcbway"

& $kicad sch erc $sch
& $kicad pcb drc $pcb
& $kicad pcb export gerbers --output $out --layers F.Cu,B.Cu,F.Mask,B.Mask,F.Silkscreen,B.Silkscreen,Edge.Cuts $pcb
& $kicad pcb export drill --output $out --format excellon --excellon-units mm --generate-map --generate-report $pcb
& $kicad sch export pdf --output "$out\schematic.pdf" $sch
```

Zip the contents of `hardware\zero3-carrier\fabrication\pcbway` after visual
Gerber inspection.

## Routing Workflow

The PCB is intentionally left unrouted by `generate_pcb.py` (apart from the
GND pour). Two safe paths finish the copper. Either way, run
`python validate_design.py` until zero unconnected items remain before
exporting Gerbers — see `manual-routing-guide.md` for the export commands.

1. **Auto-route signal nets, hand-route the power section.** Run

       python route_with_freerouting.py --effort medium

   This exports the DSN, fetches a pinned Freerouting JAR, routes the signal
   nets, imports the SES, refills the GND pour, and re-runs DRC. After it
   finishes, open the PCB in KiCad and **manually re-route the TPS54531 buck
   regulator section and the high-side MOSFET switch** against the TI
   reference layout. Auto-routers do not respect switching-supply layout
   rules.

2. **Route entirely by hand in KiCad GUI.** Follow `manual-routing-guide.md`.
   The buck regulator and high-side switch are routed first per their
   datasheets, then digital signals, then ground stitching vias.

## Gerber ZIP Available

The current Gerber upload package is committed at
`fabrication/zero3-water-logger-carrier-R1.zip` (~170 KB). Contents:

- F.Cu, B.Cu, F.Mask, B.Mask, F.Silkscreen, B.Silkscreen, Edge.Cuts gerbers
- Excellon drill file + drill map PDF + drill report
- Gerber job file (.gbrjob)
- Schematic PDF
- `REVIEW-BEFORE-ORDER.md` listing the manual review items

Auto-router output is electrically correct (DRC clean) but does not respect
switching-supply layout rules. Re-route the TPS54531 buck regulator and the
high-side MOSFET switch by hand in KiCad before ordering. See
`REVIEW-BEFORE-ORDER.md` and `manual-routing-guide.md`.

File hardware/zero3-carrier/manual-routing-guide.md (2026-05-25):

# Manual KiCad Routing Guide

This is a step-by-step guide for routing the carrier PCB by hand in the KiCad
PCB editor. Use it if you prefer not to run an external auto-router, or after
running `route_with_freerouting.py` to redo the safety-critical sections.

The starting state is the schematic-synced placement that
`generate_pcb.py` produces. ERC is clean, DRC is clean, GND copper pours are
already added on both layers, and 83 nets remain unconnected.

## What must be hand-routed regardless of any auto-router

The switching power supply and high-side switch sections do not tolerate
generic auto-routing. Even if you let Freerouting touch them, you must
re-route them by hand against the part datasheets before fabrication.

These nets:

| Net | Why it needs careful routing |
| --- | --- |
| `BUCK_SW` | Switching node. Keep the copper area as small as practical between U2 pin PH, L1, D2, and the bootstrap cap CBOOT. Large SW copper radiates EMI. |
| `PD_FUSED` | Buck input. Run wide, short, with CIN1/CIN2/CIN3 placed right at U2 pins. |
| `FUSED_5V1` | Buck output. Wide trace, low ESR caps COUT1/COUT2 at U2 output. Continues into the source of Q1. |
| `OPI_5V_SW` | Switched 5V to the Orange Pi. Wide. Tied to Q1 drain and C1 bulk capacitor. |
| `BUCK_FB` | Feedback. Run from VOUT side of RFB1 to U2 pin VSENSE, keep away from `BUCK_SW`. |
| `BUCK_BOOT`, `BUCK_COMP`, `BUCK_SS`, `BUCK_EN` | Small-signal compensation/start-up; route per TI datasheet. |
| `PWR_GATE`, `Q2_GATE` | High-side gate drive. Short tracks; keep `PWR_GATE` away from switching node. |
| `USB_VBUS`, `USB_CC1`, `USB_CC2`, `PD_CFG`, `PD_NEGOTIATED_VBUS` | PD front end. Follow CH224K supplier reference layout. |
| `GND` | Use the existing pour on both layers; add stitching vias near U1, U2, Q1, C1. |

References:

- TPS54531 datasheet, "Layout" section
  https://www.ti.com/lit/ds/symlink/tps54531.pdf
- CH224K supplier datasheet from your vendor.
- AO4407A PowerPak/SOIC-8 datasheet for thermal copper recommendation.

## Step-by-step

1. Open `zero3-water-logger-carrier.kicad_pro` in KiCad. Switch to the PCB
   editor (`Eeschema -> Open PCB Editor` or open the `.kicad_pcb` directly).
2. Press `Inspect -> Net Inspector` to see which nets are still unrouted.
3. Set the net classes if you have not already:
    - `Power`: width 1.2 mm minimum, including `FUSED_5V1`, `OPI_5V_SW`,
      `PD_FUSED`, `PD_NEGOTIATED_VBUS`, `USB_VBUS`.
    - `Default`: width 0.25 mm for signal nets.
    - Vias: 0.8 mm width / 0.4 mm drill.
4. Route the buck regulator section first:
    1. Place a short, fat `BUCK_SW` polygon between U2 PH/SW pin, L1 pin 1,
       and D2 cathode.
    2. Place CIN1, CIN2, CIN3 immediately adjacent to U2 VIN/GND.
    3. Place COUT1, COUT2 immediately adjacent to L1 output / U2 ground.
    4. Route VIN and 5V1 as wide as possible. Use both layers if needed.
    5. The U2 PowerPAD (EP) is GND. Drop several thermal vias under the pad
       into the bottom GND pour for heat dissipation.
5. Route the high-side switch around Q1 and Q2:
    1. Q1 source pads tie to `FUSED_5V1` with wide copper.
    2. Q1 drain pads tie to `OPI_5V_SW` with wide copper through C1.
    3. R2 (gate pull-up) and R3/R4 (gate drive) keep traces short.
6. Route the USB-C PD front end (U1, J14, D1, F1).
7. Route the signal nets:
    - I2C (`OPI_SDA`, `OPI_SCL`, `PICO_GP4`, `PICO_GP5`): keep both lines
      together, route in parallel where you can.
    - UART (`UART_OPI_TX_PICO_RX`, `UART_PICO_TX_OPI_RX`): short, parallel.
    - DS18B20 (`OPI_1WIRE`): single trace from OPi pin 7 to J5 and R1.
    - Sensor analog (`PH_AIN`, `TDS_AIN`, `TURB_AIN`, `ORP_AIN`, `DO_AIN`,
      `NH4_AIN`): keep away from the switching power supply area.
8. Route the optional `OPI_READY` and button/LED nets.
9. Add ground stitching vias on a roughly 10 mm grid across the board.
10. Add silkscreen labels next to each external connector (J5..J13, J15, J16).
11. Run DRC (`Inspect -> Design Rules Checker`) with "Refill zones before
    DRC" enabled. Iterate until both **violations** and **unconnected items**
    are zero.

## Final checks

Before exporting Gerbers, confirm:

- `python validate_design.py` exits with `all checks passed.`.
- Visually compare the front and back copper to the schematic.
- Use `View -> 3D Viewer` and inspect mechanical clearances.
- Confirm board outline matches your enclosure.

## Exporting Gerbers

From the repository root (Windows PowerShell):

```powershell
$kicad = "C:\Program Files\KiCad\10.0\bin\kicad-cli.exe"
$pcb   = "hardware\zero3-carrier\zero3-water-logger-carrier.kicad_pcb"
$sch   = "hardware\zero3-carrier\zero3-water-logger-carrier.kicad_sch"
$out   = "hardware\zero3-carrier\fabrication\pcbway"

& $kicad pcb export gerbers `
    --output $out `
    --layers F.Cu,B.Cu,F.Mask,B.Mask,F.Silkscreen,B.Silkscreen,Edge.Cuts `
    $pcb

& $kicad pcb export drill `
    --output $out --format excellon --excellon-units mm `
    --generate-map --generate-report $pcb

& $kicad sch export pdf --output "$out\schematic.pdf" $sch
```

Zip the contents of `hardware\zero3-carrier\fabrication\pcbway\` and inspect
the Gerbers in an independent viewer (such as PCBWay's online previewer or
gerbv) before uploading.

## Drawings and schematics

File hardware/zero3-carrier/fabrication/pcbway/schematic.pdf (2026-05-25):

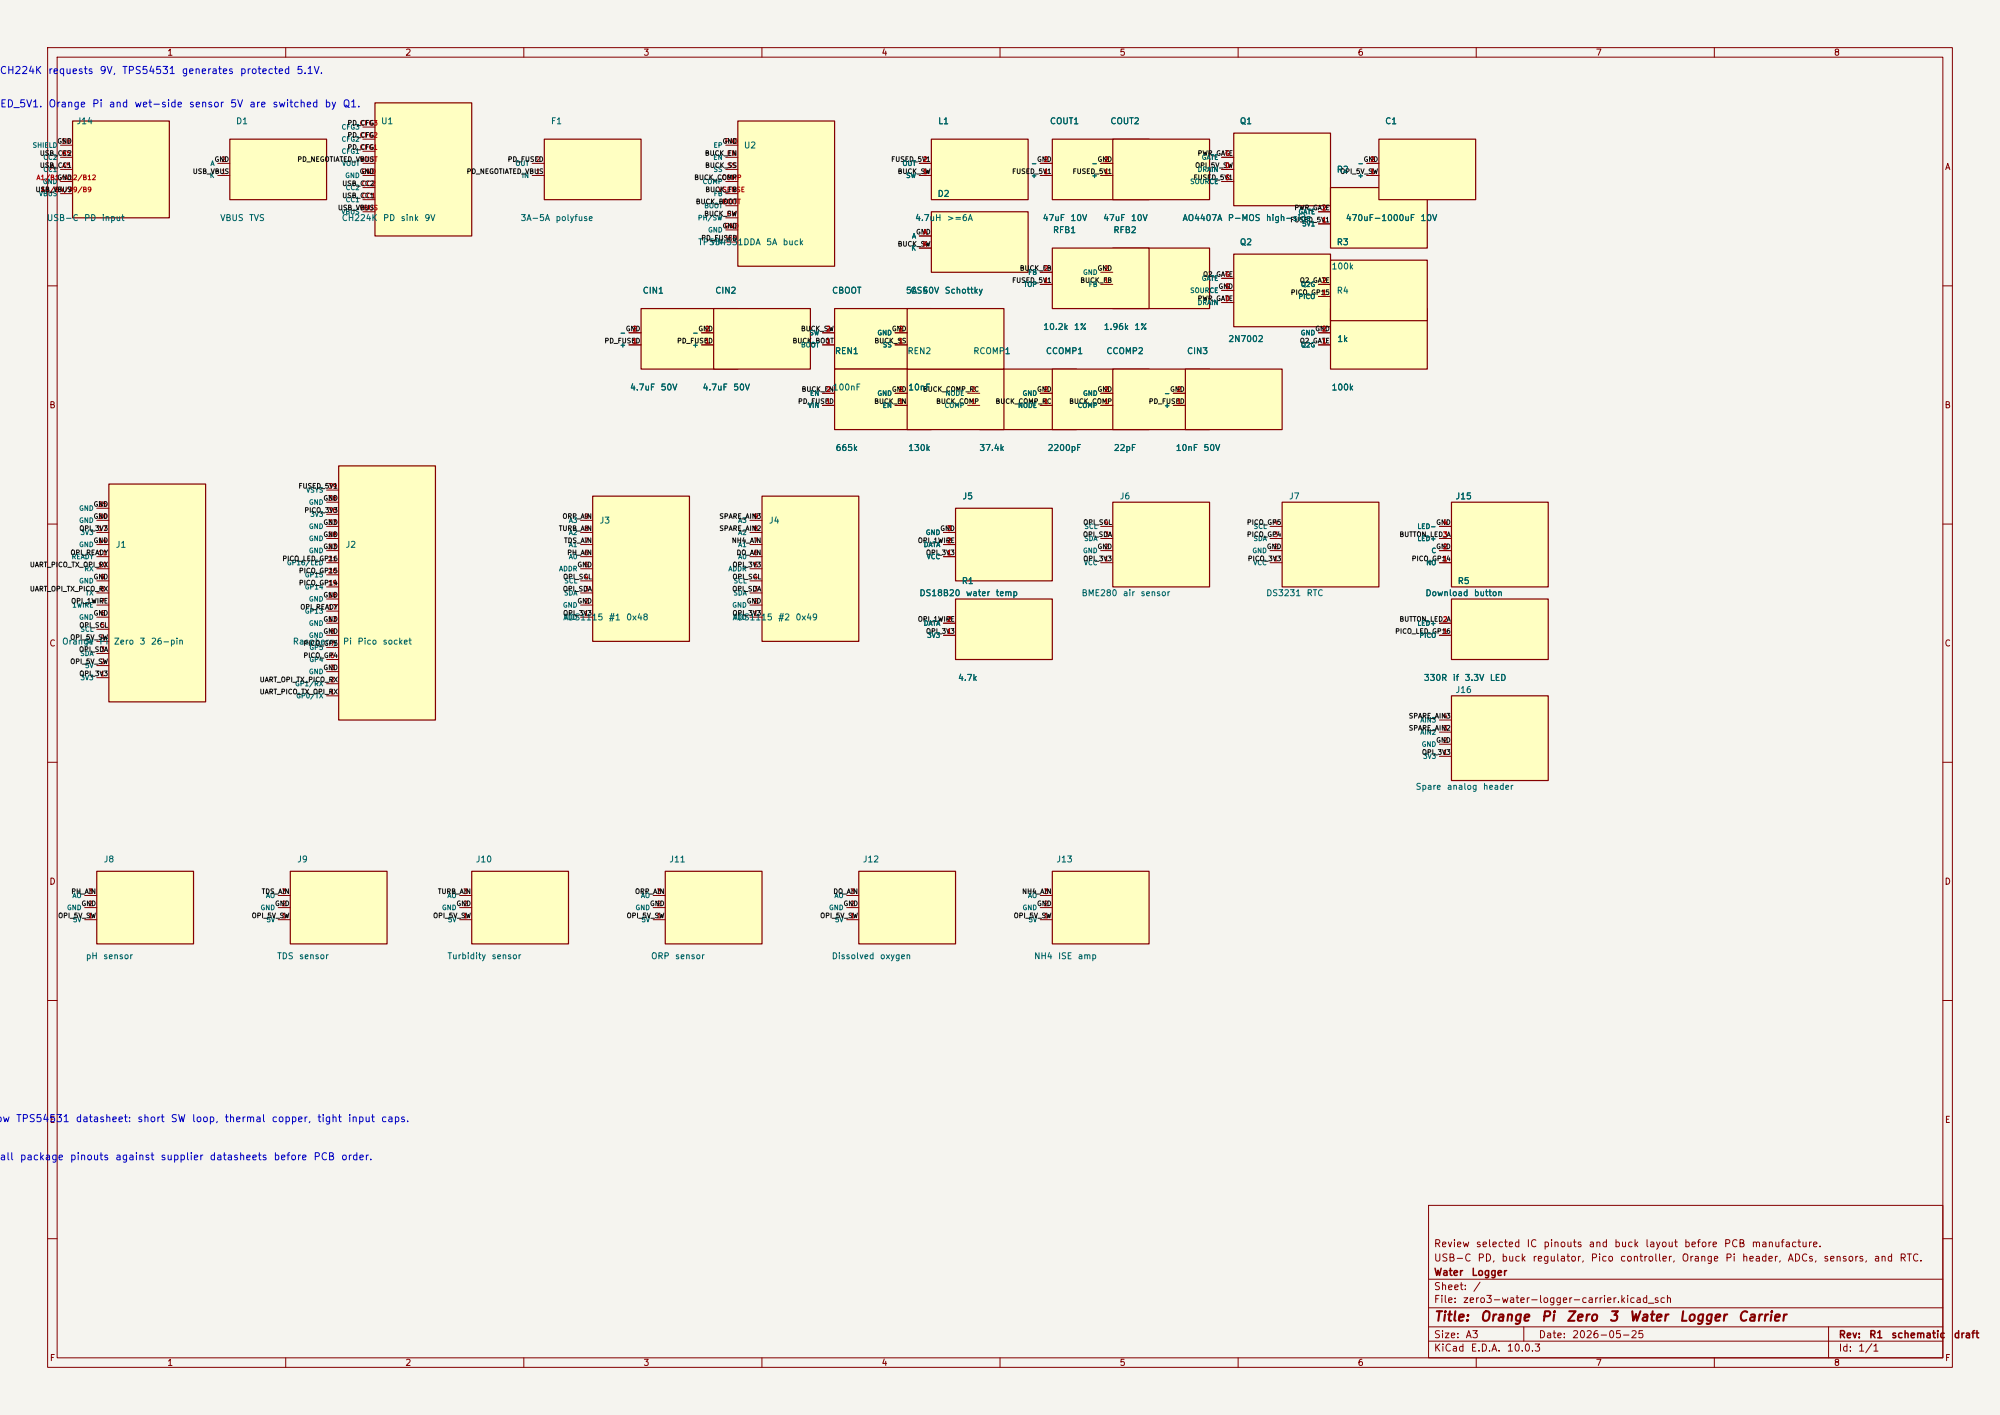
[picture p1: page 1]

PICO_GP15 Pico is always-on from FUSED_5V1. Orange Pi and wet-side sensor 5V are switched by Q1.

3V3 36 GND 38
TDS sensor GP0/TX 1 GP1/RX 2 GND 3 GP4 6 GP5 7 GND 8 GND 13 GP13 17 GND 18 GP14 19 GP15 20 GP16/LED 21 GND 23 GND 28 GND 33

TX 8 GND 9 RX 10 READY 11 GND 14

Buck regulator PCB layout must follow TPS54531 datasheet: short SW loop, thermal copper, tight input caps.

Verify CH224K strap pins and all package pinouts against supplier datasheets before PCB order.

Review selected IC pinouts and buck layout before PCB manufacture.
USB-C PD, buck regulator, Pico controller, Orange Pi header, ADCs, sensors, and RTC.
Water Logger
Sheet: /
File: zero3-water-logger-carrier.kicad_sch
Title: Orange Pi Zero 3 Water Logger Carrier

F Date: 2026-05-25

KiCad E.D.A. 10.0.3 | Id: 1/1

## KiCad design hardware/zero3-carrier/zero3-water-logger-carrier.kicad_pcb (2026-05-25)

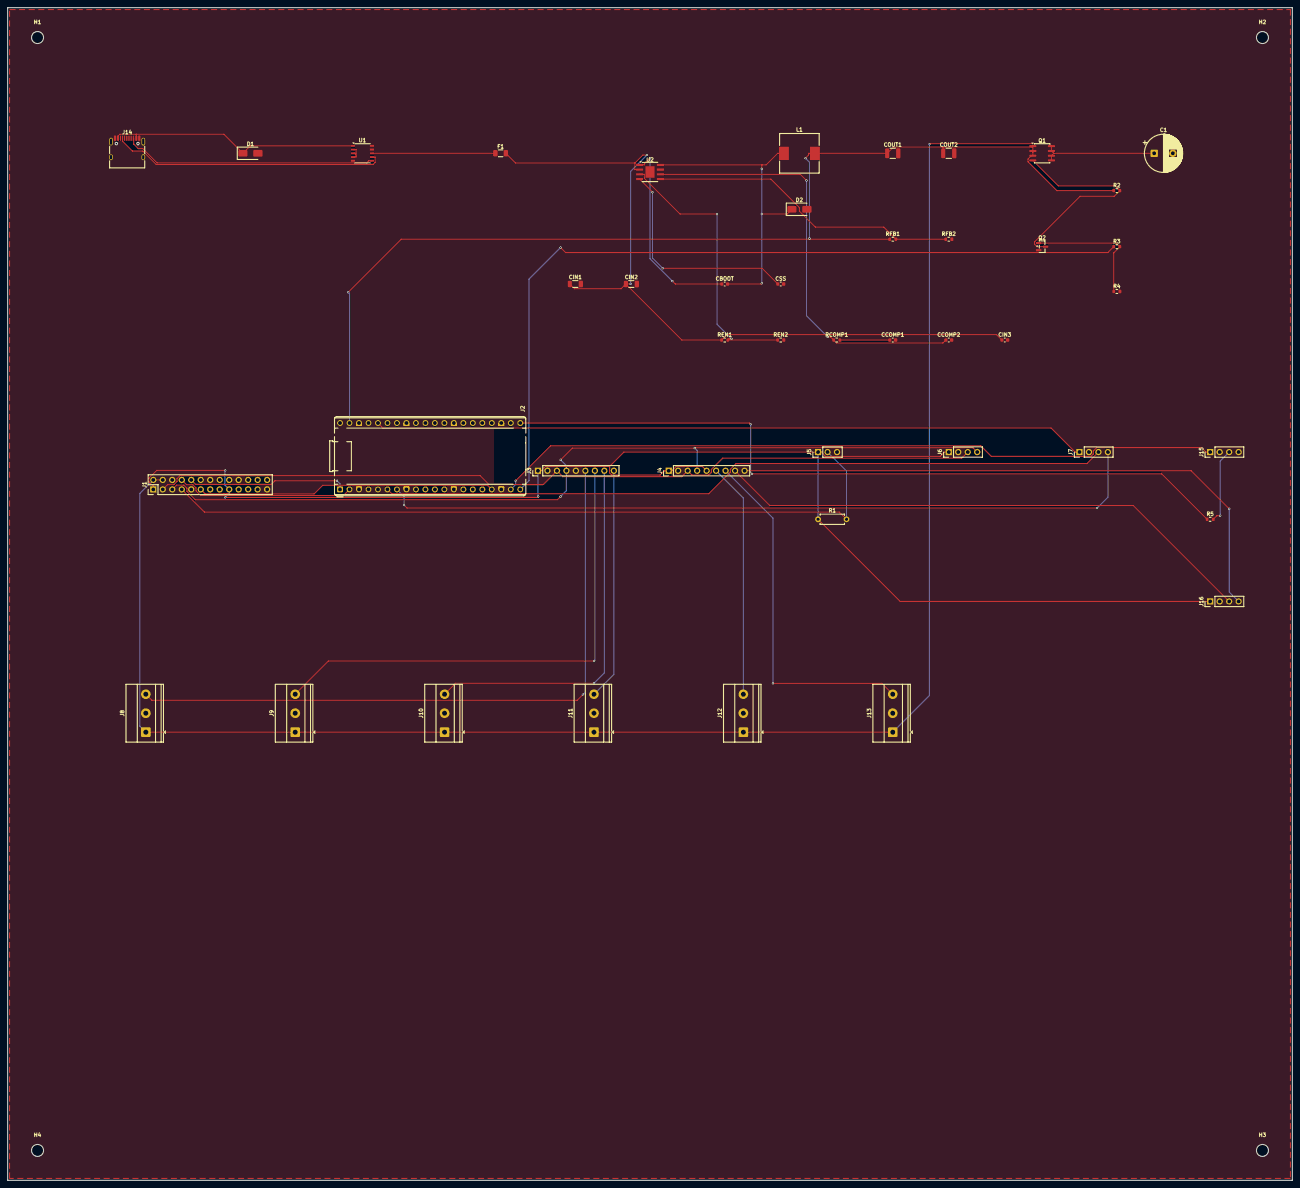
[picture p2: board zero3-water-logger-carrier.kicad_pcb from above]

Board: 2 copper layers, 344.0 x 314.0 mm, 48 parts (0 on the bottom side), 40 nets.

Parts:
C1: 470uF-1000uF 10V; CP_Radial_D10.0mm_P5.00mm
CBOOT: 100nF; C_0603_1608Metric
CCOMP1: 2200pF; C_0603_1608Metric
CCOMP2: 22pF; C_0603_1608Metric
CIN1, CIN2: 4.7uF 50V; C_1206_3216Metric
CIN3: 10nF 50V; C_0603_1608Metric
COUT1, COUT2: 47uF 10V; C_1210_3225Metric
CSS: 10nF; C_0603_1608Metric
D1: VBUS TVS; D_SMA
D2: 5A 40V Schottky; D_SMA
F1: 3A-5A polyfuse; Fuse_1206_3216Metric
H1, H2, H3, H4: MountingHole_3.2mm_M3
J1: Orange Pi Zero 3 26-pin; PinHeader_2x13_P2.54mm_Vertical
J2: Raspberry Pi Pico socket; RaspberryPi_Pico_Common_THT
J3: ADS1115 #1 0x48; PinHeader_1x09_P2.54mm_Vertical
J4: ADS1115 #2 0x49; PinHeader_1x09_P2.54mm_Vertical
J5: DS18B20 water temp; PinHeader_1x03_P2.54mm_Vertical
J6: BME280 air sensor; PinHeader_1x04_P2.54mm_Vertical
J7: DS3231 RTC; PinHeader_1x04_P2.54mm_Vertical
J8: pH sensor; TerminalBlock_Phoenix_MKDS-1,5-3-5.08_1x03_P5.08mm_Horizont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
J9: TDS sensor; TerminalBlock_Phoenix_MKDS-1,5-3-5.08_1x03_P5.08mm_Horizont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
J10: Turbidity sensor; TerminalBlock_Phoenix_MKDS-1,5-3-5.08_1x03_P5.08mm_Horizont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
J11: ORP sensor; TerminalBlock_Phoenix_MKDS-1,5-3-5.08_1x03_P5.08mm_Horizont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
J12: Dissolved oxygen; TerminalBlock_Phoenix_MKDS-1,5-3-5.08_1x03_P5.08mm_Horizont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
J13: NH4 ISE amp; TerminalBlock_Phoenix_MKDS-1,5-3-5.08_1x03_P5.08mm_Horizont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
J14: USB-C PD input; USB_C_Receptacle_HRO_TYPE-C-31-M-12
J15: Download button; PinHeader_1x04_P2.54mm_Vertical
J16: Spare analog header; PinHeader_1x04_P2.54mm_Vertical
L1: 4.7uH >=6A; L_10.4x10.4_H4.8
Q1: AO4407A P-MOS high-side; SOIC-8_3.9x4.9mm_P1.27mm
Q2: 2N7002; SOT-23
R1: 4.7k; R_Axial_DIN0207_L6.3mm_D2.5mm_P7.62mm_Horizontal
R2, R4: 100k; R_0603_1608Metric
R3: 1k; R_0603_1608Metric
R5: 330R if 3.3V LED; R_0603_1608Metric
RCOMP1: 37.4k; R_0603_1608Metric
REN1: 665k; R_0603_1608Metric
REN2: 130k; R_0603_1608Metric
RFB1: 10.2k 1%; R_0603_1608Metric
RFB2: 1.96k 1%; R_0603_1608Metric
U1: CH224K PD sink 9V; SSOP-10_3.9x4.9mm_P1.00mm
U2: TPS54531DDA 5A buck; TI_SO-PowerPAD-8

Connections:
BUCK_BOOT: CBOOT.1, U2.1
BUCK_COMP: CCOMP2.1, RCOMP1.1, U2.6
BUCK_COMP_RC: CCOMP1.1, RCOMP1.2
BUCK_EN: REN1.2, REN2.1, U2.3
BUCK_FB: RFB1.2, RFB2.1, U2.5
BUCK_SS: CSS.1, U2.4
BUCK_SW: CBOOT.2, D2.1, L1.1, U2.8
BUTTON_LED_A: J15.3, R5.2
DO_AIN: J4.6, J12.3
FUSED_5V1: COUT1.1, COUT2.1, J2.39, L1.2, Q1.1, Q1.2, Q1.3, R2.1, RFB1.1
GND: C1.2, CCOMP1.2, CCOMP2.2, CIN1.2, CIN2.2, CIN3.2, COUT1.2, COUT2.2, CSS.2, D1.2, D2.2, J1.6, J1.9, J1.14, J1.20, J1.25, J2.3, J2.8, J2.13, J2.18, J2.23, J2.28, J2.33, J2.38, J3.2, J3.5, J4.2, J5.3, J6.2, J7.2, J8.2, J9.2, J10.2, J11.2, J12.2, J13.2, J14.A1, J14.A12, J14.B1, J14.B12, J14.SH, J15.2, J15.4, J16.2, Q2.2, R4.2, REN2.2, RFB2.2, U1.5, U1.9, U1.10, U2.7, U2.9
NH4_AIN: J4.7, J13.3
OPI_1WIRE: J1.7, J5.2, R1.2
OPI_3V3: J1.1, J1.17, J3.1, J4.1, J4.5, J5.1, J6.1, J16.1, R1.1
OPI_5V_SW: C1.1, J1.2, J1.4, J8.1, J9.1, J10.1, J11.1, J12.1, J13.1, Q1.5, Q1.6, Q1.7, Q1.8
OPI_READY: J1.11, J2.17
OPI_SCL: J1.5, J3.4, J4.4, J6.4
OPI_SDA: J1.3, J3.3, J4.3, J6.3
ORP_AIN: J3.9, J11.3
PD_CFG: U1.2, U1.3, U1.4
PD_FUSED: CIN1.1, CIN2.1, CIN3.1, F1.2, REN1.1, U2.2
PD_NEGOTIATED_VBUS: F1.1, U1.8
PH_AIN: J3.6, J8.3
PICO_3V3: J2.36, J7.1
PICO_GP4: J2.6, J7.3
PICO_GP5: J2.7, J7.4
PICO_GP14: J2.19, J15.1
PICO_GP15: J2.20, R3.1
PICO_LED_GP16: J2.21, R5.1
PWR_GATE: Q1.4, Q2.3, R2.2
Q2_GATE: Q2.1, R3.2, R4.1
SPARE_AIN2: J4.8, J16.3
SPARE_AIN3: J4.9, J16.4
TDS_AIN: J3.7, J9.3
TURB_AIN: J3.8, J10.3
UART_OPI_TX_PICO_RX: J1.8, J2.2
UART_PICO_TX_OPI_RX: J1.10, J2.1
USB_CC1: J14.A5, U1.7
USB_CC2: J14.B5, U1.6
USB_VBUS: D1.1, J14.A4, J14.A9, J14.B4, J14.B9, U1.1

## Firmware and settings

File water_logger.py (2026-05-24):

#!/usr/bin/env python3
"""
Orange Pi water-quality logger.

Every 6 hours this app appends one CSV row to the microSD card. It logs
raw sensor voltages, calibrated sensor values, and derived water-quality
calculations that can be computed from the available probes.
"""

from __future__ import annotations

import csv
import math
import os
import subprocess
import time
import argparse
from dataclasses import dataclass
from datetime import datetime, timedelta, timezone
from pathlib import Path


# Store records on the Orange Pi microSD card.
# If you copy the project to /home/orangepi/water-logger, weekly CSV files are
# kept in /home/orangepi/water-logger/records/.
PROJECT_PATH = Path(__file__).resolve().parent
RECORDS_PATH = PROJECT_PATH / "records"
CSV_FILENAME_PREFIX = "water_conditions"
DOWNLOAD_MODE_FILENAME = "DOWNLOAD_MODE"
PAIRING_MODE_FILENAME = "PAIRING_MODE"
NEXT_INTERVAL_FILENAME = "next_interval_seconds.txt"

# 6 hours, in seconds.
LOG_INTERVAL_SECONDS = 6 * 60 * 60
LOW_PRESSURE_INTERVAL_SECONDS = 60 * 60
LOW_PRESSURE_HPA = 1000.0
try:
    PRESSURE_DROP_HPA_24H = float(os.environ.get("ALERT_PRESSURE_DROP_HPA_24H", "6.0"))
except ValueError:
    PRESSURE_DROP_HPA_24H = 6.0
PICO_SERIAL_PORT = os.environ.get("PICO_SERIAL_PORT", "/dev/ttyS5")

# Taking several quick samples and averaging them reduces random ADC noise.
# Keep this modest for battery use.
SAMPLE_COUNT = 5
SAMPLE_DELAY_SECONDS = 0.2

# TDS-to-EC factor. 500 is common for hobby TDS meters, but calibrate yours.
TDS_FACTOR = 500.0

# Orange Pi boards expose different I2C bus numbers. Zero 3 commonly uses I2C3;
# Orange Pi 5 Max setups commonly use another enabled header bus. Set
# I2C_BUS_NUMBER to force one bus, otherwise the logger tries likely buses and
# uses the first bus where configured sensors respond.
I2C_BUS_NUMBER_TEXT = os.environ.get("I2C_BUS_NUMBER", "").strip()
try:
    I2C_BUS_NUMBER = int(I2C_BUS_NUMBER_TEXT) if I2C_BUS_NUMBER_TEXT else None
except ValueError:
    I2C_BUS_NUMBER = None
I2C_BUS_CANDIDATES = [3, 5, 1, 0, 2, 4, 6, 7]

# ADS1115 addresses. Set ADS1115 #1 ADDR to GND for 0x48.
# Set ADS1115 #2 ADDR to 3.3V/VDD for 0x49.
ADS1115_1_ADDRESS = 0x48
ADS1115_2_ADDRESS = 0x49

# ADS1115 full-scale range. Use +/-4.096V, but never feed an ADS1115 input
# above its VDD. If powered from 3.3V, sensor outputs must stay within 0-3.3V.
ADS1115_FULL_SCALE_VOLTS = 4.096


@dataclass
class SensorVoltages:
    ph: float | None
    tds: float | None
    turbidity: float | None
    orp: float | None
    dissolved_oxygen: float | None
    ammonium_ise: float | None
    ph_status: str
    tds_status: str
    turbidity_status: str
    orp_status: str
    dissolved_oxygen_status: str
    ammonium_ise_status: str


@dataclass
class WaterReading:
    timestamp: str
    temperature_c: float | None
    temperature_status: str
    ph_voltage: float | None
    tds_voltage: float | None
    turbidity_voltage: float | None
    orp_voltage: float | None
    do_voltage: float | None
    ammonium_voltage: float | None
    ph_status: str
    tds_status: str
    turbidity_status: str
    orp_status: str
    dissolved_oxygen_status: str
    ammonium_ise_status: str
    ph: float | None
    tds_ppm: float | None
    ec_ms_cm: float | None
    salinity_ppt: float | None
    turbidity_ntu: float | None
    clarity_percent: float | None
    orp_mv: float | None
    dissolved_oxygen_mg_l: float | None
    dissolved_oxygen_percent: float | None
    ammonium_nh4_mg_l: float | None
    toxic_ammonia_nh3_mg_l: float | None
    ammonia_risk: str
    water_score: float | None
    water_condition: str
    air_temperature_c: float | None
    air_humidity_percent: float | None
    air_pressure_hpa: float | None
    air_sensor_status: str
    dew_point_c: float | None
    air_water_temp_difference_c: float | None
    next_interval_seconds: int


class ADS1115:
    """Tiny ADS1115 reader using Linux I2C.

    This avoids Raspberry-Pi-specific GPIO libraries and works well on Orange Pi
    once /dev/i2c-3 is enabled.
    """

    CONVERSION_REGISTER = 0x00
    CONFIG_REGISTER = 0x01

    CHANNEL_CONFIG = {
        0: 0x4000,
        1: 0x5000,
        2: 0x6000,
        3: 0x7000,
    }

    def __init__(self, bus_number: int, address: int) -> None:
        try:
            from smbus2 import SMBus
        except ImportError:
            try:
                from smbus import SMBus
            except ImportError as exc:
                raise RuntimeError(
                    "Install I2C support first: sudo apt install python3-smbus i2c-tools"
                ) from exc

        self.bus = SMBus(bus_number)
        self.address = address

    def read_voltage(self, channel: int) -> float:
        if channel not in self.CHANNEL_CONFIG:
            raise ValueError(f"ADS1115 channel must be 0-3, got {channel}")

        # Single-shot conversion, single-ended channel, +/-4.096V range,
        # 128 samples/sec, comparator disabled.
        config = (
            0x8000
            | self.CHANNEL_CONFIG[channel]
            | 0x0200
            | 0x0100
            | 0x0080
            | 0x0003
        )

        self.bus.write_i2c_block_data(
            self.address,
            self.CONFIG_REGISTER,
            [(config >> 8) & 0xFF, config & 0xFF],
        )
        time.sleep(0.01)

        data = self.bus.read_i2c_block_data(self.address, self.CONVERSION_REGISTER, 2)
        raw = (data[0] << 8) | data[1]
        if raw & 0x8000:
            raw -= 0x10000

        return raw * ADS1115_FULL_SCALE_VOLTS / 32768.0


def clamp(value: float, low: float, high: float) -> float:
    return max(low, min(high, value))


def i2c_bus_candidates() -> list[int]:
    if I2C_BUS_NUMBER is not None:
        return [I2C_BUS_NUMBER]
    available = []
    for path in sorted(Path("/dev").glob("i2c-*")):
        try:
            available.append(int(path.name.split("-", 1)[1]))
        except (IndexError, ValueError):
            continue
    candidates = available or I2C_BUS_CANDIDATES
    ordered: list[int] = []
    for bus in [*I2C_BUS_CANDIDATES, *candidates]:
        if bus not in ordered:
            ordered.append(bus)
    return ordered


def read_bme280() -> dict[str, float | str | None]:
    """Read BME280 ambient air sensor from I2C3.

    Returns None values if the sensor/library is not available yet. Without a
    pressure reading, the logger uses the normal 6-hour interval.
    """
    try:
        from smbus2 import SMBus
    except ImportError:
        try:
            from smbus import SMBus
        except ImportError:
            return {
                "air_temperature_c": None,
                "air_humidity_percent": None,
                "air_pressure_hpa": None,
                "air_sensor_status": "i2c_library_missing",
            }

    try:
        import bme280
    except ImportError:
        return {
            "air_temperature_c": None,
            "air_humidity_percent": None,
            "air_pressure_hpa": None,
            "air_sensor_status": "bme280_library_missing",
        }

    for bus_number in i2c_bus_candidates():
        for address in (0x76, 0x77):
            bus = None
            try:
                bus = SMBus(bus_number)
                calibration = bme280.load_calibration_params(bus, address)
                data = bme280.sample(bus, address, calibration)
                return {
                    "air_temperature_c": float(data.temperature),
                    "air_humidity_percent": float(data.humidity),
                    "air_pressure_hpa": float(data.pressure),
                    "air_sensor_status": "ok",
                }
            except Exception:
                continue
            finally:
                if bus is not None and hasattr(bus, "close"):
                    bus.close()

    return {
        "air_temperature_c": None,
        "air_humidity_percent": None,
        "air_pressure_hpa": None,
        "air_sensor_status": "bme280_not_found_or_not_responding",
    }


def dew_point_c(air_temperature_c: float | None, humidity_percent: float | None) -> float | None:
    if air_temperature_c is None or humidity_percent is None or humidity_percent <= 0:
        return None

    a = 17.27
    b = 237.7
    alpha = ((a * air_temperature_c) / (b + air_temperature_c)) + math.log(humidity_percent / 100.0)
    return (b * alpha) / (a - alpha)


def parse_timestamp(value: str) -> datetime | None:
    if not value:
        return None
    try:
        parsed = datetime.fromisoformat(value.replace("Z", "+00:00"))
    except ValueError:
        return None
    if parsed.tzinfo is None:
        return parsed.replace(tzinfo=timezone.utc)
    return parsed.astimezone(timezone.utc)


def recent_pressure_values(now: datetime, hours: int = 24) -> list[float]:
    window_start = now - timedelta(hours=hours)
    values: list[float] = []
    for path in weekly_csv_files()[-4:]:
        try:
            with path.open("r", newline="", encoding="utf-8") as file:
                for row in csv.DictReader(file):
                    timestamp = parse_timestamp(row.get("timestamp", ""))
                    if timestamp is None or timestamp < window_start:
                        continue
                    pressure_text = row.get("air_pressure_hpa", "").strip()
                    if pressure_text:
                        values.append(float(pressure_text))
        except (OSError, ValueError):
            continue
    return values


def choose_next_interval_seconds(pressure_hpa: float | None, now: datetime | None = None) -> int:
    if pressure_hpa is not None and pressure_hpa < LOW_PRESSURE_HPA:
        return LOW_PRESSURE_INTERVAL_SECONDS
    if pressure_hpa is not None:
        now = datetime.now(timezone.utc) if now is None else now
        prior_pressures = recent_pressure_values(now)
        if prior_pressures and max(prior_pressures) - pressure_hpa >= PRESSURE_DROP_HPA_24H:
            return LOW_PRESSURE_INTERVAL_SECONDS
    return LOG_INTERVAL_SECONDS


def read_temperature_c() -> tuple[float | None, str]:
    """Read DS18B20 temperature from Linux 1-Wire.

    On the Orange Pi this usually appears under /sys/bus/w1/devices/ after
    1-Wire support is enabled. Returns None if no DS18B20 is found yet.
    """
    try:
        devices = list(Path("/sys/bus/w1/devices").glob("28-*"))
    except OSError:
        return None, "onewire_path_unavailable"

    if not devices:
        return None, "ds18b20_not_found"

    try:
        data = (devices[0] / "w1_slave").read_text(encoding="utf-8").strip()
    except OSError:
        return None, "ds18b20_read_failed"

    if "YES" not in data:
        return None, "ds18b20_crc_failed"

    marker = "t="
    if marker in data:
        return int(data.split(marker, 1)[1]) / 1000.0, "ok"

    return None, "ds18b20_temperature_missing"


def read_sensor_voltages(ads1: ADS1115 | None = None, ads2: ADS1115 | None = None) -> SensorVoltages:
    """Read analog voltages from ADC boards.

    Wiring layout:
      ADS1115 #1: A0 pH, A1 TDS, A2 turbidity, A3 ORP
      ADS1115 #2: A0 dissolved oxygen, A1 ammonium ISE
    """
    ads1_status = "ok"
    ads2_status = "ok"
    bus_numbers = i2c_bus_candidates()

    if ads1 is None:
        for bus_number in bus_numbers:
            try:
                ads1 = ADS1115(bus_number, ADS1115_1_ADDRESS)
                break
            except Exception:
                ads1 = None
        if ads1 is None:
            ads1_status = "ads1115_0x48_not_found_or_i2c_failed"
    if ads2 is None:
        for bus_number in bus_numbers:
            try:
                ads2 = ADS1115(bus_number, ADS1115_2_ADDRESS)
                break
            except Exception:
                ads2 = None
        if ads2 is None:
            ads2_status = "ads1115_0x49_not_found_or_i2c_failed"

    def read_channel(
        ads: ADS1115 | None,
        address: int,
        channel: int,
        adc_status: str,
    ) -> tuple[float | None, str]:
        if ads is None:
            return None, adc_status
        try:
            return ads.read_voltage(channel), "ok"
        except Exception:
            return None, f"ads1115_0x{address:02x}_channel_{channel}_read_failed"

    ph, ph_status = read_channel(ads1, ADS1115_1_ADDRESS, 0, ads1_status)
    tds, tds_status = read_channel(ads1, ADS1115_1_ADDRESS, 1, ads1_status)
    turbidity, turbidity_status = read_channel(ads1, ADS1115_1_ADDRESS, 2, ads1_status)
    orp, orp_status = read_channel(ads1, ADS1115_1_ADDRESS, 3, ads1_status)
    dissolved_oxygen, dissolved_oxygen_status = read_channel(ads2, ADS1115_2_ADDRESS, 0, ads2_status)
    ammonium_ise, ammonium_ise_status = read_channel(ads2, ADS1115_2_ADDRESS, 1, ads2_status)

    return SensorVoltages(
        ph=ph,
        tds=tds,
        turbidity=turbidity,
        orp=orp,
        dissolved_oxygen=dissolved_oxygen,
        ammonium_ise=ammonium_ise,
        ph_status=ph_status,
        tds_status=tds_status,
        turbidity_status=turbidity_status,
        orp_status=orp_status,
        dissolved_oxygen_status=dissolved_oxygen_status,
        ammonium_ise_status=ammonium_ise_status,
    )


def read_average_sensor_voltages() -> SensorVoltages:
    ads1 = None
    ads2 = None
    for bus_number in i2c_bus_candidates():
        if ads1 is None:
            try:
                ads1 = ADS1115(bus_number, ADS1115_1_ADDRESS)
            except Exception:
                pass
        if ads2 is None:
            try:
                ads2 = ADS1115(bus_number, ADS1115_2_ADDRESS)
            except Exception:
                pass
        if ads1 is not None and ads2 is not None:
            break

    samples = []
    for sample_index in range(SAMPLE_COUNT):
        samples.append(read_sensor_voltages(ads1, ads2))
        if sample_index < SAMPLE_COUNT - 1 and SAMPLE_DELAY_SECONDS:
            time.sleep(SAMPLE_DELAY_SECONDS)

    def average(sensor_name: str) -> float | None:
        values = [getattr(sample, sensor_name) for sample in samples]
        values = [value for value in values if value is not None]
        if not values:
            return None
        return sum(values) / len(values)

    def combined_status(status_name: str) -> str:
        statuses = [getattr(sample, status_name) for sample in samples]
        if all(status == "ok" for status in statuses):
            return "ok"
        failed = [status for status in statuses if status != "ok"]
        if len(failed) == len(statuses):
            return failed[0]
        return "partial_read_failure"

    return SensorVoltages(
        ph=average("ph"),
        tds=average("tds"),
        turbidity=average("turbidity"),
        orp=average("orp"),
        dissolved_oxygen=average("dissolved_oxygen"),
        ammonium_ise=average("ammonium_ise"),
        ph_status=combined_status("ph_status"),
        tds_status=combined_status("tds_status"),
        turbidity_status=combined_status("turbidity_status"),
        orp_status=combined_status("orp_status"),
        dissolved_oxygen_status=combined_status("dissolved_oxygen_status"),
        ammonium_ise_status=combined_status("ammonium_ise_status"),
    )


def estimate_ph(voltage: float | None) -> float | None:
    if voltage is None:
        return None
    # Placeholder only. Calibrate with pH 4, 7, and 10 buffer solutions.
    ph7_voltage = 2.50
    slope_ph_per_volt = -5.70
    return 7.0 + ((voltage - ph7_voltage) * slope_ph_per_volt)


def estimate_tds_ppm(voltage: float | None, temperature_c: float | None) -> float | None:
    if voltage is None:
        return None
    # Gravity-style TDS polynomial with temperature compensation.
    temp = 25.0 if temperature_c is None else temperature_c
    compensation = 1.0 + 0.02 * (temp - 25.0)
    compensated_voltage = voltage / compensation
    tds = (
        133.42 * compensated_voltage**3
        - 255.86 * compensated_voltage**2
        + 857.39 * compensated_voltage
    ) * 0.5
    return max(tds, 0.0)


def estimate_turbidity_ntu(voltage: float | None) -> float | None:
    if voltage is None:
        return None
    # Common hobby-sensor approximation. Calibrate with your module.
    ntu = -1120.4 * voltage**2 + 5742.3 * voltage - 4352.9
    return max(ntu, 0.0)


def estimate_orp_mv(voltage: float | None) -> float | None:
    if voltage is None:
        return None
    # Placeholder only. Calibrate with known ORP solution.
    neutral_voltage = 2.50
    return (voltage - neutral_voltage) * 1000.0


def do_saturation_mg_l(temperature_c: float | None) -> float:
    # Freshwater oxygen saturation at sea level, approximated by interpolation.
    temp = 25.0 if temperature_c is None else clamp(temperature_c, 0.0, 40.0)
    table = {
        0.0: 14.62,
        5.0: 12.80,
        10.0: 11.29,
        15.0: 10.08,
        20.0: 9.09,
        25.0: 8.26,
        30.0: 7.56,
        35.0: 6.95,
        40.0: 6.41,
    }
    points = sorted(table)
    for low, high in zip(points, points[1:]):
        if low <= temp <= high:
            fraction = (temp - low) / (high - low)
            return table[low] + ((table[high] - table[low]) * fraction)
    return table[25.0]


def estimate_dissolved_oxygen_mg_l(voltage: float | None, temperature_c: float | None) -> float | None:
    if voltage is None:
        return None
    # Placeholder calibration. Replace with your Gravity DO calibration voltage.
    calibration_voltage_in_air_saturated_water = 1.60
    return max(
        0.0,
        voltage / calibration_voltage_in_air_saturated_water * do_saturation_mg_l(temperature_c),
    )


def estimate_ammonium_nh4_mg_l(voltage: float | None, temperature_c: float | None) -> float | None:
    if voltage is None:
        return None
    # Placeholder ISE conversion. This requires a proper ISE amplifier and
    # calibration solution. Tune these after calibration.
    electrode_mv = voltage * 1000.0
    calibration_mv = 1500.0
    calibration_mg_l = 10.0
    temp = 25.0 if temperature_c is None else temperature_c
    slope_mv_per_decade = 59.16 * ((temp + 273.15) / 298.15)

    log_concentration = (
        (electrode_mv - calibration_mv) / slope_mv_per_decade
        + math.log10(calibration_mg_l)
    )
    return max(0.0, 10**log_concentration)


def ammonia_nh3_fraction(ph: float | None, temperature_c: float | None) -> float | None:
    if ph is None:
        return None
    temp = 25.0 if temperature_c is None else temperature_c
    pka = 0.09018 + (2729.92 / (temp + 273.15))
    return 1.0 / (1.0 + 10 ** (pka - ph))


def ammonia_risk(nh3_mg_l: float | None) -> str:
    if nh3_mg_l is None:
        return "unknown"
    if nh3_mg_l < 0.02:
        return "low"
    if nh3_mg_l < 0.05:
        return "caution"
    if nh3_mg_l < 0.10:
        return "danger"
    return "critical"


def water_quality_score(
    ph: float | None,
    tds_ppm: float | None,
    turbidity_ntu: float | None,
    temperature_c: float | None,
    do_mg_l: float | None,
    nh3_mg_l: float | None,
) -> float | None:
    values = [ph, tds_ppm, turbidity_ntu, temperature_c, do_mg_l, nh3_mg_l]
    if any(value is None for value in values):
        return None

    score = 100.0

    if ph < 6.5:
        score -= (6.5 - ph) * 15.0
    elif ph > 8.5:
        score -= (ph - 8.5) * 15.0

    if tds_ppm > 500.0:
        score -= (tds_ppm - 500.0) * 0.04

    if turbidity_ntu > 5.0:
        score -= (turbidity_ntu - 5.0) * 2.0

    if temperature_c < 5.0:
        score -= (5.0 - temperature_c) * 2.0
    elif temperature_c > 30.0:
        score -= (temperature_c - 30.0) * 2.0

    if do_mg_l < 5.0:
        score -= (5.0 - do_mg_l) * 12.0

    if nh3_mg_l > 0.02:
        score -= (nh3_mg_l - 0.02) * 700.0

    return round(clamp(score, 0.0, 100.0), 2)


def water_condition(score: float | None) -> str:
    if score is None:
        return "unknown"
    if score >= 90:
        return "excellent"
    if score >= 75:
        return "good"
    if score >= 50:
        return "poor"
    return "bad"
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

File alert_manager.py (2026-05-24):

#!/usr/bin/env python3
"""
Freshwater alert and daily-status logic for the cellular branch.

Thresholds are conservative starter values for field alerts. Calibrate and tune
them for your creek, probes, and local freshwater ecology before relying on
them for decisions.
"""

from __future__ import annotations

import csv
import json
import os
from dataclasses import dataclass
from datetime import datetime, timedelta, timezone
from pathlib import Path
from typing import Any
from zoneinfo import ZoneInfo, ZoneInfoNotFoundError

from water_logger import CSV_FILENAME_PREFIX, RECORDS_PATH, weekly_csv_files


STATE_PATH = RECORDS_PATH / "cellular_alert_state.json"
SENSOR_STATUS_COLUMNS = [
    "temperature_status",
    "ph_status",
    "tds_status",
    "turbidity_status",
    "orp_status",
    "dissolved_oxygen_status",
    "ammonium_ise_status",
    "air_sensor_status",
]


def env_float(name: str, default: float) -> float:
    try:
        return float(os.environ.get(name, default))
    except ValueError:
        return default


def env_int(name: str, default: int) -> int:
    try:
        return int(os.environ.get(name, default))
    except ValueError:
        return default


BASELINE_SAMPLE_ROWS = env_int("SENSOR_BASELINE_SAMPLE_ROWS", 8)


@dataclass(frozen=True)
class AlertThresholds:
    ph_min: float = env_float("ALERT_PH_MIN", 6.5)
    ph_max: float = env_float("ALERT_PH_MAX", 9.0)
    do_min_mg_l: float = env_float("ALERT_DO_MIN_MG_L", 5.0)
    nh3_max_mg_l: float = env_float("ALERT_NH3_MAX_MG_L", 0.05)
    water_temp_min_c: float = env_float("ALERT_WATER_TEMP_MIN_C", 5.0)
    water_temp_max_c: float = env_float("ALERT_WATER_TEMP_MAX_C", 30.0)
    turbidity_max_ntu: float = env_float("ALERT_TURBIDITY_MAX_NTU", 50.0)
    tds_max_ppm: float = env_float("ALERT_TDS_MAX_PPM", 1000.0)
    pressure_drop_hpa_24h: float = env_float("ALERT_PRESSURE_DROP_HPA_24H", 6.0)
    temp_change_c_24h: float = env_float("ALERT_TEMP_CHANGE_C_24H", 2.0)
    alert_cooldown_seconds: int = env_int("ALERT_COOLDOWN_SECONDS", 6 * 60 * 60)
    daily_status_after_hour: int = env_int("DAILY_STATUS_AFTER_HOUR", 4)
    timezone_name: str = os.environ.get("ALERT_TIMEZONE", "Australia/Brisbane")


def parse_time(value: str) -> datetime | None:
    if not value:
        return None
    try:
        parsed = datetime.fromisoformat(value.replace("Z", "+00:00"))
    except ValueError:
        return None
    if parsed.tzinfo is None:
        return parsed.replace(tzinfo=timezone.utc)
    return parsed.astimezone(timezone.utc)


def as_float(row: dict[str, str], key: str) -> float | None:
    value = row.get(key, "").strip()
    if value == "":
        return None
    try:
        return float(value)
    except ValueError:
        return None


def read_rows(limit: int = 96) -> list[dict[str, str]]:
    rows: list[dict[str, str]] = []
    for path in weekly_csv_files()[-4:]:
        with path.open("r", newline="", encoding="utf-8") as file:
            rows.extend(csv.DictReader(file))
    return rows[-limit:]


def load_state() -> dict[str, Any]:
    try:
        return json.loads(STATE_PATH.read_text(encoding="utf-8"))
    except (OSError, json.JSONDecodeError):
        return {"last_sms_alerts": {}, "last_daily_status_date": "", "sensor_baseline": {}}


def save_state(state: dict[str, Any]) -> None:
    STATE_PATH.parent.mkdir(parents=True, exist_ok=True)
    STATE_PATH.write_text(json.dumps(state, indent=2, sort_keys=True), encoding="utf-8")


def alert(key: str, severity: str, message: str) -> dict[str, str]:
    return {"key": key, "severity": severity, "message": message}


def alert_timezone(thresholds: AlertThresholds):
    try:
        return ZoneInfo(thresholds.timezone_name)
    except ZoneInfoNotFoundError:
        if thresholds.timezone_name == "Australia/Brisbane":
            return timezone(timedelta(hours=10))
        return timezone.utc


def sensor_baseline_from_rows(rows: list[dict[str, str]]) -> dict[str, bool]:
    baseline: dict[str, bool] = {}
    for key in SENSOR_STATUS_COLUMNS:
        baseline[key] = any(row.get(key, "").strip() == "ok" for row in rows[:BASELINE_SAMPLE_ROWS])
    return baseline


def get_sensor_baseline(rows: list[dict[str, str]], state: dict[str, Any]) -> dict[str, bool]:
    baseline = state.get("sensor_baseline")
    if isinstance(baseline, dict) and state.get("sensor_baseline_finalized"):
        return {str(key): bool(value) for key, value in baseline.items()}
    if not rows:
        return {}
    previous = {str(key): bool(value) for key, value in baseline.items()} if isinstance(baseline, dict) else {}
    detected = sensor_baseline_from_rows(rows)
    baseline = {key: previous.get(key, False) or detected.get(key, False) for key in SENSOR_STATUS_COLUMNS}
    state["sensor_baseline"] = baseline
    if len(rows) >= BASELINE_SAMPLE_ROWS:
        state["sensor_baseline_finalized"] = True
    return baseline
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

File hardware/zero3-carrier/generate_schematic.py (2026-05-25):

from __future__ import annotations

import datetime
import uuid
from pathlib import Path


OUT = Path(__file__).with_name("zero3-water-logger-carrier.kicad_sch")
SYM_OUT = Path(__file__).with_name("water_logger_generated.kicad_sym")
SYM_TABLE_OUT = Path(__file__).with_name("sym-lib-table")
PINOUT_CSV_OUT = Path(__file__).with_name("zero3-water-logger-carrier-pinout.csv")
TODAY = datetime.date.today().isoformat()
GRID = 2.54
PIN_SPACING = 2.54


def u() -> str:
    return str(uuid.uuid4())


def grid(value: float) -> float:
    return round(value / GRID) * GRID


def lib_id(ref: str) -> str:
    return f"WL:{ref}"


COMPONENTS = [
    {
        "ref": "J14",
        "value": "USB-C PD input",
        "footprint": "Connector_USB:USB_C_Receptacle_HRO_TYPE-C-31-M-12",
        "x": 25,
        "y": 35,
        "pins": [
            ("A4/B4/A9/B9", "VBUS", "USB_VBUS"),
            ("A1/B1/A12/B12", "GND", "GND"),
            ("A5", "CC1", "USB_CC1"),
            ("B5", "CC2", "USB_CC2"),
            ("SH", "SHIELD", "GND"),
        ],
    },
    {
        "ref": "D1",
        "value": "VBUS TVS",
        "footprint": "Diode_SMD:D_SMA",
        "x": 58,
        "y": 35,
        "pins": [("1", "K", "USB_VBUS"), ("2", "A", "GND")],
    },
    {
        "ref": "U1",
        "value": "CH224K PD sink 9V",
        "footprint": "Package_SO:SSOP-10_3.9x4.9mm_P1.00mm",
        "x": 88,
        "y": 35,
        "pins": [
            ("VBUS", "VBUS", "USB_VBUS"),
            ("CC1", "CC1", "USB_CC1"),
            ("CC2", "CC2", "USB_CC2"),
            ("GND", "GND", "GND"),
            ("VOUT", "VOUT", "PD_NEGOTIATED_VBUS"),
            ("CFG1", "CFG1", "PD_CFG"),
            ("CFG2", "CFG2", "PD_CFG"),
            ("CFG3", "CFG3", "PD_CFG"),
        ],
    },
    {
        "ref": "F1",
        "value": "3A-5A polyfuse",
        "footprint": "Fuse:Fuse_1206_3216Metric",
        "x": 125,
        "y": 35,
        "pins": [("1", "IN", "PD_NEGOTIATED_VBUS"), ("2", "OUT", "PD_FUSED")],
    },
    {
        "ref": "U2",
        "value": "TPS54531DDA 5A buck",
        "footprint": "Package_SO:TI_SO-PowerPAD-8",
        "x": 165,
        "y": 40,
        "pins": [
            ("VIN", "VIN", "PD_FUSED"),
            ("GND", "GND", "GND"),
            ("PH", "PH/SW", "BUCK_SW"),
            ("BOOT", "BOOT", "BUCK_BOOT"),
            ("VSENSE", "FB", "BUCK_FB"),
            ("COMP", "COMP", "BUCK_COMP"),
            ("SS", "SS", "BUCK_SS"),
            ("EN", "EN", "BUCK_EN"),
            ("PAD", "EP", "GND"),
        ],
    },
    {
        "ref": "L1",
        "value": "4.7uH >=6A",
        "footprint": "Inductor_SMD:L_10.4x10.4_H4.8",
        "x": 205,
        "y": 35,
        "pins": [("1", "SW", "BUCK_SW"), ("2", "OUT", "FUSED_5V1")],
    },
    {
        "ref": "D2",
        "value": "5A 40V Schottky",
        "footprint": "Diode_SMD:D_SMA",
        "x": 205,
        "y": 50,
        "pins": [("K", "K", "BUCK_SW"), ("A", "A", "GND")],
    },
    {
        "ref": "CIN1",
        "value": "4.7uF 50V",
        "footprint": "Capacitor_SMD:C_1206_3216Metric",
        "x": 145,
        "y": 70,
        "pins": [("1", "+", "PD_FUSED"), ("2", "-", "GND")],
    },
    {
        "ref": "CIN2",
        "value": "4.7uF 50V",
        "footprint": "Capacitor_SMD:C_1206_3216Metric",
        "x": 160,
        "y": 70,
        "pins": [("1", "+", "PD_FUSED"), ("2", "-", "GND")],
    },
    {
        "ref": "CBOOT",
        "value": "100nF",
        "footprint": "Capacitor_SMD:C_0603_1608Metric",
        "x": 185,
        "y": 70,
        "pins": [("1", "BOOT", "BUCK_BOOT"), ("2", "SW", "BUCK_SW")],
    },
    {
        "ref": "CSS",
        "value": "10nF",
        "footprint": "Capacitor_SMD:C_0603_1608Metric",
        "x": 200,
        "y": 70,
        "pins": [("1", "SS", "BUCK_SS"), ("2", "GND", "GND")],
    },
    {"ref": "REN1", "value": "665k", "footprint": "Resistor_SMD:R_0603_1608Metric", "x": 185, "y": 85, "pins": [("1", "VIN", "PD_FUSED"), ("2", "EN", "BUCK_EN")]},
    {"ref": "REN2", "value": "130k", "footprint": "Resistor_SMD:R_0603_1608Metric", "x": 200, "y": 85, "pins": [("1", "EN", "BUCK_EN"), ("2", "GND", "GND")]},
    {"ref": "RCOMP1", "value": "37.4k", "footprint": "Resistor_SMD:R_0603_1608Metric", "x": 215, "y": 85, "pins": [("1", "COMP", "BUCK_COMP"), ("2", "NODE", "BUCK_COMP_RC")]},
    {"ref": "CCOMP1", "value": "2200pF", "footprint": "Capacitor_SMD:C_0603_1608Metric", "x": 230, "y": 85, "pins": [("1", "NODE", "BUCK_COMP_RC"), ("2", "GND", "GND")]},
    {"ref": "CCOMP2", "value": "22pF", "footprint": "Capacitor_SMD:C_0603_1608Metric", "x": 245, "y": 85, "pins": [("1", "COMP", "BUCK_COMP"), ("2", "GND", "GND")]},
    {"ref": "CIN3", "value": "10nF 50V", "footprint": "Capacitor_SMD:C_0603_1608Metric", "x": 260, "y": 85, "pins": [("1", "+", "PD_FUSED"), ("2", "-", "GND")]},
    {
        "ref": "COUT1",
        "value": "47uF 10V",
        "footprint": "Capacitor_SMD:C_1210_3225Metric",
        "x": 230,
        "y": 35,
        "pins": [("1", "+", "FUSED_5V1"), ("2", "-", "GND")],
    },
    {
        "ref": "COUT2",
        "value": "47uF 10V",
        "footprint": "Capacitor_SMD:C_1210_3225Metric",
        "x": 245,
        "y": 35,
        "pins": [("1", "+", "FUSED_5V1"), ("2", "-", "GND")],
    },
    {
        "ref": "RFB1",
        "value": "10.2k 1%",
        "footprint": "Resistor_SMD:R_0603_1608Metric",
        "x": 230,
        "y": 58,
        "pins": [("1", "TOP", "FUSED_5V1"), ("2", "FB", "BUCK_FB")],
    },
    {
        "ref": "RFB2",
        "value": "1.96k 1%",
        "footprint": "Resistor_SMD:R_0603_1608Metric",
        "x": 245,
        "y": 58,
        "pins": [("1", "FB", "BUCK_FB"), ("2", "GND", "GND")],
    },
    {
        "ref": "Q1",
        "value": "AO4407A P-MOS high-side",
        "footprint": "Package_SO:SOIC-8_3.9x4.9mm_P1.27mm",
        "x": 270,
        "y": 35,
        "pins": [("S", "SOURCE", "FUSED_5V1"), ("D", "DRAIN", "OPI_5V_SW"), ("G", "GATE", "PWR_GATE")],
    },
    {
        "ref": "Q2",
        "value": "2N7002",
        "footprint": "Package_TO_SOT_SMD:SOT-23",
        "x": 270,
        "y": 60,
        "pins": [("D", "DRAIN", "PWR_GATE"), ("S", "SOURCE", "GND"), ("G", "GATE", "Q2_GATE")],
    },
    {"ref": "R2", "value": "100k", "footprint": "Resistor_SMD:R_0603_1608Metric", "x": 290, "y": 45, "pins": [("1", "5V1", "FUSED_5V1"), ("2", "GATE", "PWR_GATE")]},
    {"ref": "R3", "value": "1k", "footprint": "Resistor_SMD:R_0603_1608Metric", "x": 290, "y": 60, "pins": [("1", "PICO", "PICO_GP15"), ("2", "Q2G", "Q2_GATE")]},
    {"ref": "R4", "value": "100k", "footprint": "Resistor_SMD:R_0603_1608Metric", "x": 290, "y": 72, "pins": [("1", "Q2G", "Q2_GATE"), ("2", "GND", "GND")]},
    {"ref": "C1", "value": "470uF-1000uF 10V", "footprint": "Capacitor_THT:CP_Radial_D10.0mm_P5.00mm", "x": 300, "y": 35, "pins": [("1", "+", "OPI_5V_SW"), ("2", "-", "GND")]},
    {
        "ref": "J1",
        "value": "Orange Pi Zero 3 26-pin",
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

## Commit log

2026-05-12 Tidy wiring diagram
2026-05-14 Document relay and MOS power switch wiring
2026-05-14 Add button pairing mode
2026-05-14 Increase manual power off hold time
2026-05-14 Add Android sensor section dashboard
2026-05-14 Baseline installed sensors for alerts
2026-05-24 Fix logger review issues
    [alert_manager.py, bluetooth_records_server.py, cellular_uploader.py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]
2026-05-24 Support both Orange Pi boards with optional cellular
2026-05-24 Clean up main docs and wiring diagram
2026-05-24 Fix audit findings
    Critical:
    - Fix NameError in adaptive interval logic. water_logger.py called
    weekly_csv_files() without defining or importing it, crashing
    collect_reading() on every wake where pressure was at or above
    1000 hPa. Move the helper into water_logger.py and import it from
    the three modules that previously duplicated it.
    Hardening:
    - bluetooth_records_server.py: wrap live-mode send_text so a phone
    disconnect during streaming does not crash the BT server.
    - pico_power_controller.py: drain UART while waiting for the 10-second
    manual power-off hold during a scheduled wake, so a NEXT_INTERVAL
    message from the Orange Pi is not lost.
    - cellular_uploader.py: set AT+CSCS=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
    [alert_manager.py, bluetooth_records_server.py, cellular_uploader.py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]
2026-05-24 Add Gradle wrapper for android-app
    Local builds previously required installing Gradle 8.10.2 manually. The
    wrapper pins the Gradle version inside the repo so a fresh clone can
    build with just a JDK and ./gradlew. CI now uses the wrapper too instead
    of installing Gradle separately.
    - android-app/gradlew, gradlew.bat, gradle/wrapper/ generated by
    `gradle wrapper --gradle-version 8.10.2 --distribution-type bin`.
    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
2026-05-24 Clean up wiring diagram SVG and README intro
    - Reroute the two ADS1115 SCL wires so they no longer pass through the
    ADS1115 #1 and #2 box interiors (visual artifact only; electrical
    connections were unchanged).
    - Route the Pico 3V3 -> DS3231 VCC wire from a labelled Pico 3V3 pin
    over the top of the diagram, instead of a 32-pixel orphan stub at
    the RTC box.
    - Rewrite the wiring-diagram README intro: the SVG already reflects
    the listed bullet points, so frame them as "things to double-check"
    rather than "corrections to apply".
2026-05-24 Add PCB carrier design brief
2026-05-24 Add Zero 3 PCB carrier scaffold
    [zero3-water-logger-carrier-pinout.csv, zero3-water-logger-carrier.kicad_pcb, zero3-water-logger-carrier.kicad_sch]
2026-05-24 Ignore KiCad PCB lock files
2026-05-24 Redraw wiring diagram with all components as separate blocks
    Every sensor, module, and component is now its own block:
    - Split the combined Pico/RTC/Button box into separate DS3231 RTC and
    Momentary Button blocks.
    - Split the Sensor Modules box into 6 individual blocks: pH, TDS,
    Turbidity, ORP, Dissolved Oxygen, NH4+ ISE amplifier.
    - Total 16 component blocks in a 5-column layout.
    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
2026-05-24 Space out wiring diagram for readability
    - Canvas widened from 2000x1320 to 2400x1450.
    - Column gaps grown from 30-50 px to 120-160 px so wires have room
    to breathe.
    - Pin spacing on Pico, Orange Pi, and ADS1115 boxes increased from
    26 px to 36-40 px between adjacent pins.
    - Sensor module analog wires now drawn as monotonically-ordered
    diagonals across the Col D-E gap; with the sources and targets in
    the same top-to-bottom order, the diagonals do not cross each other.
    - Switch-to-OPi power moved from a horizontal lane route to a clean
    short vertical drop at x=1010 (5V) and x=1100 (GND).
    - All cross-column wires use distinct vertical lane assignments with
    generous 10-40 px separat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
2026-05-25 Add schematic synced Zero 3 carrier PCB draft
    [selected-parts-bom.csv, zero3-water-logger-carrier-pinout.csv, zero3-water-logger-carrier.kicad_pcb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]
2026-05-25 Fix hardware script audit findings; auto-generate pinout CSV
    - Pinout CSV is now generated by generate_schematic.py from the same
    COMPONENTS table the schematic uses, so the published pinout cannot
    drift from actual net assignments. The previous hand-written CSV had
    J2 (Pico) pin numbers and J8-J13 (sensor) 5V net names that did not
    match the schematic.
    - generate_pcb.py now resolves the KiCad footprint library cross-
    platform (Windows / macOS / Linux), honouring KICAD_FOOTPRINT_DIR if
    set, and prints a warning instead of silently skipping when a
    mounting-hole footprint is missing.
    - Removed the disabled route_to_backbone() dead code from
    generate_pcb.py. The routing workflow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
    [zero3-water-logger-carrier-pinout.csv, zero3-water-logger-carrier.kicad_pcb, zero3-water-logger-carrier.kicad_sch]
2026-05-25 Add GND pours, Freerouting wrapper, validator, manual routing guide
    PCB:
    - generate_pcb.py now adds filled GND copper pours on both layers with
    solid (non-thermal) pad connection. This brings unconnected-pad count
    down from 136 to 83 with zero DRC violations.
    Tooling:
    - route_with_freerouting.py: one-command auto-routing. Exports the PCB
    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
    [zero3-water-logger-carrier.kicad_pcb]
2026-05-25 Route PCB end-to-end via Freerouting; export PCBWay Gerber package
    PCB routing:
    - route_with_freerouting.py runs end-to-end: exports Specctra DSN via
    pcbnew.ExportSpecctraDSN (KiCad 10's kicad-cli dropped that
    subcommand), invokes Freerouting v2.1.0 (pinned because v2.2.x
    requires Java 25), imports the SES via pcbnew.ImportSpecctraSES,
    refills the GND pour, and re-runs DRC.
    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
    [zero3-water-logger-carrier-B_Cu.gbl, zero3-water-logger-carrier-B_Mask.gbs, zero3-water-logger-carrier-B_Silkscreen.gbo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]
2026-05-25 Re-route PCB at Freerouting --effort thorough; refresh Gerber package
    - 100-pass auto-routing run converged at score 963.82 (vs 957.26 at
    medium effort, a ~0.7% quality improvement).
    - ERC: 0 violations. DRC: 0 violations, 0 unconnected items.
    - Re-exported the full Gerber + drill + schematic PDF package and
    refreshed the upload zip (~178 KB).
    Manual review items in REVIEW-BEFORE-ORDER.md still apply; the TPS54531
    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
    [zero3-water-logger-carrier-B_Cu.gbl, zero3-water-logger-carrier-B_Mask.gbs, zero3-water-logger-carrier-B_Silkscreen.gbo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]
